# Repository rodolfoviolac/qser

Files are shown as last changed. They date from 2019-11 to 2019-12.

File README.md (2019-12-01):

# QSER

QSER is a application and hardware shield interface to manage and fully control a engine motor (Quanser Robots) on Galileo v2 shield.
On this repository you will find the shield hardware design under `/shield` and the software resources under `/src`.

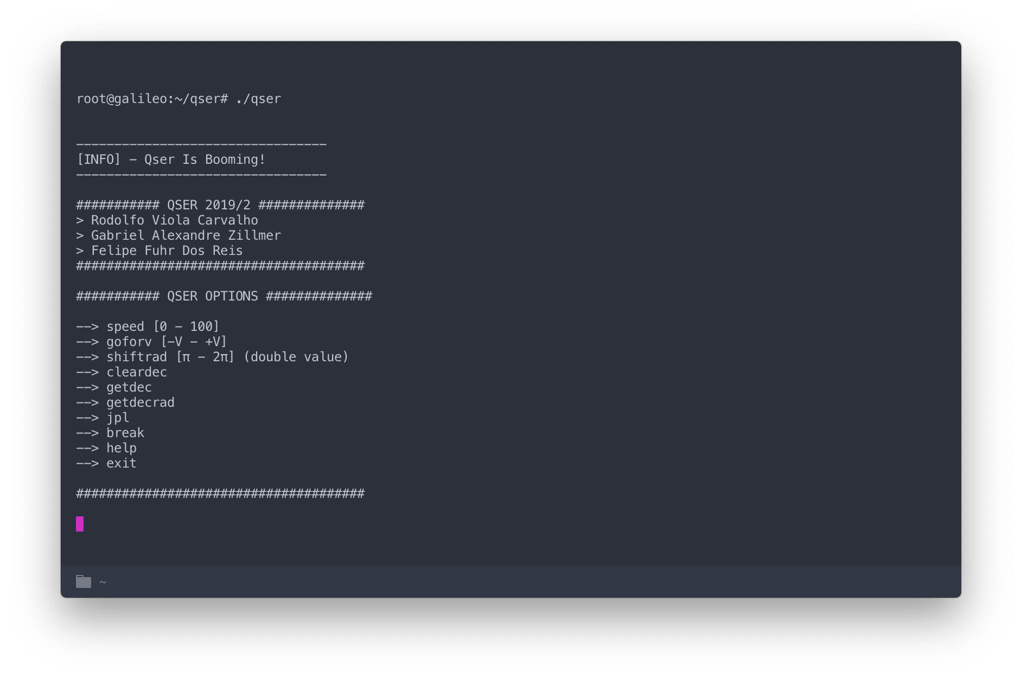
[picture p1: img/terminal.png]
Terminal


## Build

### Project Local 
This project is using cmake to automate build releases and versioning.
- Compile the full project with `/cmake-build-release/make`.
- Clean built files with `/cmake-build-release/make clean`.

### Project Target Galileo
- Compile the full project with `make`.
- Clean built files with `make clean`.

### Documentation
Compile the project documentation to `docs/` folder.
```
  $ make docs
```

## Modules

#### Debugger:
This project contain a built in debugger for handling execution path helping the developers find out eventual bugs or errors.
To enable this feature you need to enable the debugger options under `/src/helpers/helpers.h`.

#### Run Local:
This project contain a local template simulation to help developers simulate the code that will run on the Galileo shield, this feature enable developers to build and run the code without the physical shield device. 
To enable this feature you need to enable the Run Local option under `/src/helpers/helpers.h`.

## Roadmap

See the [open issues](https://github.com/rodolfoviolac/qser/issues) for a list of proposed features (and known issues).

## Contributing

For major changes, please open an issue first to discuss what you would like to change.
Please make sure to update tests as appropriate.

1. Fork the Project
2. Create your Feature Branch (`git checkout -b feature/AmazingFeature`)
3. Commit your Changes (`git commit -m 'Add some AmazingFeature'`)
4. Push to the Branch (`git push origin feature/AmazingFeature`)
5. Open a Pull Request

## Team

> Or Contributors

| <a href="https://github.com/rodolfoviolac" target="_blank">**Rodolfo Viola**</a> | <a href="https://github.com/gazillmer" target="_blank">**Gabriel Zillmer**</a> | <a href="https://github.com/felipefuhr" target="_blank">**Felipe Fuhr**</a> |
| :---: |:---:| :---:|
| rodolfoviolac (https://github.com/rodolfoviolac) | gazillmer (https://github.com/gazillmer) | [![felipefuhr]()](https://github.com/felipefuhr)  |
| <a href="https://github.com/rodolfoviolac" target="_blank">`github.com/rodolfoviolac`</a> | <a href="https://github.com/gazillmer" target="_blank">`github.com/gazillmer`</a> | <a href="https://github.com/felipefuhr" target="_blank">`github.com/felipefuhr`</a> |

## License
[MIT](https://github.com/rodolfoviolac/qser/LICENSE.md)

Project Link: [https://github.com/rodolfoviolac/qser](https://github.com/rodolfoviolac/qser)

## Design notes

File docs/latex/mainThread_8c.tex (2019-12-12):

\hypertarget{mainThread_8c}{}\doxysection{src/main\+Thread/main\+Thread.c File Reference}
\label{mainThread_8c}\index{src/mainThread/mainThread.c@{src/mainThread/mainThread.c}}

Thread Principal para controlar fluxo do usuário e comandos.  

{\ttfamily \#include \char`\"{}main\+Thread.\+h\char`\"{}}\newline
\doxysubsection*{Functions}
\begin{DoxyCompactItemize}
\item 
void $\ast$ \mbox{\hyperlink{mainThread_8c_a59426b0c771489c349fbd9ddc7cf9f7a}{handler\+Main\+Thread}} ()
\begin{DoxyCompactList}\small\item\em Main Thread para interface com usuário e controle de fluxo. Thread responsável por esperar comando do usuário e fazer a chamad necessária da A\+PI para executar a ação. \end{DoxyCompactList}\end{DoxyCompactItemize}
\doxysubsection*{Variables}
\begin{DoxyCompactItemize}
\item 
\mbox{\Hypertarget{mainThread_8c_a1516fc9ce70a57d79877afa8ef7921f7}\label{mainThread_8c_a1516fc9ce70a57d79877afa8ef7921f7}} 
int \mbox{\hyperlink{mainThread_8c_a1516fc9ce70a57d79877afa8ef7921f7}{J\+P\+L\+\_\+\+R\+E\+A\+C\+H\+E\+D\+\_\+\+S\+T\+A\+T\+U\+S\+\_\+\+O\+NE}} = 0
\begin{DoxyCompactList}\small\item\em Status do final de curso um. \end{DoxyCompactList}\item 
\mbox{\Hypertarget{mainThread_8c_aa084c4495d7058b83b56b41864c10846}\label{mainThread_8c_aa084c4495d7058b83b56b41864c10846}} 
int \mbox{\hyperlink{mainThread_8c_aa084c4495d7058b83b56b41864c10846}{J\+P\+L\+\_\+\+R\+E\+A\+C\+H\+E\+D\+\_\+\+S\+T\+A\+T\+U\+S\+\_\+\+T\+WO}} = 0
\begin{DoxyCompactList}\small\item\em Status do final de curso dois. \end{DoxyCompactList}\end{DoxyCompactItemize}

\doxysubsection{Detailed Description}
Thread Principal para controlar fluxo do usuário e comandos. 

\begin{DoxyAuthor}{Author}
Rodolfo Viola Carvalho, Gabriel Alexandre Zillmer, Felipe Fuhr Dos Reis 
\end{DoxyAuthor}
\begin{DoxyDate}{Date}
11 Dec 2019 
\end{DoxyDate}

\doxysubsection{Function Documentation}
\mbox{\Hypertarget{mainThread_8c_a59426b0c771489c349fbd9ddc7cf9f7a}\label{mainThread_8c_a59426b0c771489c349fbd9ddc7cf9f7a}} 
\index{mainThread.c@{mainThread.c}!handlerMainThread@{handlerMainThread}}
\index{handlerMainThread@{handlerMainThread}!mainThread.c@{mainThread.c}}
\doxysubsubsection{\texorpdfstring{handlerMainThread()}{handlerMainThread()}}
{\footnotesize\ttfamily void$\ast$ handler\+Main\+Thread (\begin{DoxyParamCaption}{ }\end{DoxyParamCaption})}

Main Thread para interface com usuário e controle de fluxo. Thread responsável por esperar comando do usuário e fazer a chamad necessária da A\+PI para executar a ação. 

É nessa thread que é feita excutada as funções da biblioteca, repetidamente espera em um loop infito um comando de um usuário para sair e encerrar o programa é necessario um comando Exit.

\begin{DoxyReturn}{Returns}
Retorna um Ponteiro para Null 
\end{DoxyReturn}
Função para Setar Posição de Target em Radianos.

Essa Rotina é responsável por fazer o cálculo de conversão de Radianos para uma posição do motor; Do datasheet do motor temos que 1 revolução é igual a 4096 counts. (4096 / 360) = 1 grau ou 0.\+0174533 rad

Leitura do decoder e transformação para Radianos.

Essa Rotina é responsável por fazer o cálculo de conversão da leitura do decoder para posição em radianos; Do datasheet do motor temos que 1 revolução é igual a 4096 counts. (4096 / 360) = 1 grau ou 0.\+0174533 rad

Definition at line 40 of file main\+Thread.\+c.

\begin{DoxyCode}{0}
\DoxyCodeLine{40                           \{}
\DoxyCodeLine{41     \textcolor{keywordflow}{if}(\mbox{\hyperlink{helpers_8h_ad72dbcf6d0153db1b8d8a58001feed83}{DEBUG}}) printf(\textcolor{stringliteral}{"[DEBUG] -\/ Starting handlerMainThread \(\backslash\)n"});}
\DoxyCodeLine{42     \mbox{\hyperlink{userInterface_8c_ad08d5cb2ed8e6805573049fd31dab2db}{printUserGroupsName}}();}
\DoxyCodeLine{43     \mbox{\hyperlink{userInterface_8c_a4b9e2beb67256f2c06b39d24bc83e28d}{printUserOptions}}();}
\DoxyCodeLine{44 }
\DoxyCodeLine{45     \textcolor{keywordtype}{char} command[100];}
\DoxyCodeLine{46     \textcolor{keywordflow}{while} (fgets(command, \textcolor{keyword}{sizeof}(command), stdin)) \{}
\DoxyCodeLine{47         \textcolor{keywordflow}{if}(\mbox{\hyperlink{helpers_8h_ad72dbcf6d0153db1b8d8a58001feed83}{DEBUG}}) printf(\textcolor{stringliteral}{"[DEBUG] -\/ Inside Command While MainThread \(\backslash\)n"});}
\DoxyCodeLine{48         \textcolor{keywordflow}{switch} (\mbox{\hyperlink{userInterface_8c_ace06aeff812973e632f2da24f34dcd39}{resolveOption}}(command)) \{}
\DoxyCodeLine{49             \textcolor{keywordflow}{case} OPTION\_SPEED: \{}
\DoxyCodeLine{50                 \textcolor{keywordflow}{if}(\mbox{\hyperlink{helpers_8h_ad72dbcf6d0153db1b8d8a58001feed83}{DEBUG}}) printf(\textcolor{stringliteral}{"[DEBUG] -\/ Got SPEED Option MainThread \(\backslash\)n"});}
\DoxyCodeLine{51                 \textcolor{keywordtype}{float} commandAmount = atof(\&command[6]);}
\DoxyCodeLine{52                 \textcolor{keywordflow}{if}(commandAmount > 100 || commandAmount < 0) \{}
\DoxyCodeLine{53                     printf(\textcolor{stringliteral}{"[ERROR] -\/ Speed Amount Must Be [0-\/100]\(\backslash\)n"});}
\DoxyCodeLine{54                 \} \textcolor{keywordflow}{else} \{}
\DoxyCodeLine{55                     \textcolor{keywordflow}{if}(\mbox{\hyperlink{helpers_8h_ad72dbcf6d0153db1b8d8a58001feed83}{DEBUG}}) printf(\textcolor{stringliteral}{"[DEBUG] -\/ Got Valid Speed Number MainThread \(\backslash\)n"});}
\DoxyCodeLine{56                     \textcolor{keywordtype}{float} dcAmount = (commandAmount/100)*atof(\mbox{\hyperlink{quanserInterface_8h_aacaca0988244bd3a888ca5befa89f44b}{PWM\_PERIOD}});}
\DoxyCodeLine{57                     \textcolor{keywordflow}{if}(\mbox{\hyperlink{quanserInterface_8c_a72cb6672e7a2002cb3eed86f8d58781f}{handlePwm}}((\textcolor{keywordtype}{int})dcAmount) == 1) \{}
\DoxyCodeLine{58                         fprintf(stdout, \textcolor{stringliteral}{"[INFO] MT -\/ Motor Duty Cycle \%d\%\%\(\backslash\)n\(\backslash\)n"}, (\textcolor{keywordtype}{int})dcAmount/10000);}
\DoxyCodeLine{59                     \} \textcolor{keywordflow}{else} \{}
\DoxyCodeLine{60                         printf(\textcolor{stringliteral}{"[ERROR] MT -\/ Error Turning On Motor\(\backslash\)n\(\backslash\)n"});}
\DoxyCodeLine{61                     \}}
\DoxyCodeLine{62                 \}}
\DoxyCodeLine{63                 \textcolor{keywordflow}{break};}
\DoxyCodeLine{64             \}}
\DoxyCodeLine{65             \textcolor{keywordflow}{case} OPTION\_JPL: \{}
\DoxyCodeLine{66                 \textcolor{keywordflow}{if}(\mbox{\hyperlink{helpers_8h_ad72dbcf6d0153db1b8d8a58001feed83}{DEBUG}}) printf(\textcolor{stringliteral}{"[DEBUG] -\/ Got JPL Option MainThread \(\backslash\)n"});}
\DoxyCodeLine{67                 \textcolor{keywordflow}{if}(\mbox{\hyperlink{mainThread_8c_a1516fc9ce70a57d79877afa8ef7921f7}{JPL\_REACHED\_STATUS\_ONE}} == JPL\_REACHED)\{}
\DoxyCodeLine{68                     printf(\textcolor{stringliteral}{"[INFO] MT -\/ JPL ONE Reached The End. State: Active [ \%d ]\(\backslash\)n"}, \mbox{\hyperlink{mainThread_8c_a1516fc9ce70a57d79877afa8ef7921f7}{JPL\_REACHED\_STATUS\_ONE}});}
\DoxyCodeLine{69                 \} \textcolor{keywordflow}{else} printf(\textcolor{stringliteral}{"[INFO] MT -\/ READ JPL ONE. State: Inactive [ \%d ]\(\backslash\)n"}, \mbox{\hyperlink{mainThread_8c_a1516fc9ce70a57d79877afa8ef7921f7}{JPL\_REACHED\_STATUS\_ONE}});}
\DoxyCodeLine{70                 \textcolor{keywordflow}{if}(\mbox{\hyperlink{mainThread_8c_aa084c4495d7058b83b56b41864c10846}{JPL\_REACHED\_STATUS\_TWO}} == JPL\_REACHED)\{}
\DoxyCodeLine{71                     printf(\textcolor{stringliteral}{"[INFO] MT -\/ JPL TWO Reached The End. State: Active [ \%d ]\(\backslash\)n\(\backslash\)n"}, \mbox{\hyperlink{mainThread_8c_aa084c4495d7058b83b56b41864c10846}{JPL\_REACHED\_STATUS\_TWO}});}
\DoxyCodeLine{72                 \} \textcolor{keywordflow}{else} printf(\textcolor{stringliteral}{"[INFO] MT -\/ READ JPL TWO. State: Inactive [ \%d ]\(\backslash\)n\(\backslash\)n"}, \mbox{\hyperlink{mainThread_8c_aa084c4495d7058b83b56b41864c10846}{JPL\_REACHED\_STATUS\_TWO}});}
\DoxyCodeLine{73                 \textcolor{keywordflow}{break};}
\DoxyCodeLine{74             \}}
\DoxyCodeLine{75             \textcolor{keywordflow}{case} OPTION\_GO\_FOR\_V: \{}
\DoxyCodeLine{76                 \textcolor{keywordflow}{if}(\mbox{\hyperlink{helpers_8h_ad72dbcf6d0153db1b8d8a58001feed83}{DEBUG}}) printf(\textcolor{stringliteral}{"[DEBUG] -\/ Got GO FOR V Option MainThread \(\backslash\)n"});}
\DoxyCodeLine{77                 \textcolor{keywordtype}{float} commandAmount = atof(\&command[7]);}
\DoxyCodeLine{78                 \textcolor{keywordflow}{if}(commandAmount < -\/QSER\_VOLTAGE || commandAmount > \mbox{\hyperlink{quanserInterface_8h_a85d3bb9e37fcff0e990ccd0ecb50f169}{QSER\_VOLTAGE}}) \{}
\DoxyCodeLine{79                     fprintf(stderr, \textcolor{stringliteral}{"[ERROR] -\/ Voltage Must Be On The Interval [\%+d,\%+d]\(\backslash\)n"}, (\textcolor{keywordtype}{int}) -\/\mbox{\hyperlink{quanserInterface_8h_a85d3bb9e37fcff0e990ccd0ecb50f169}{QSER\_VOLTAGE}}, (\textcolor{keywordtype}{int}) \mbox{\hyperlink{quanserInterface_8h_a85d3bb9e37fcff0e990ccd0ecb50f169}{QSER\_VOLTAGE}});}
\DoxyCodeLine{80                 \} \textcolor{keywordflow}{else} \{}
\DoxyCodeLine{81                     \textcolor{keywordflow}{if}(\mbox{\hyperlink{helpers_8h_ad72dbcf6d0153db1b8d8a58001feed83}{DEBUG}}) printf(\textcolor{stringliteral}{"[DEBUG] MT -\/ Got Accepted Voltage \(\backslash\)n"});}
\DoxyCodeLine{82                     \textcolor{keywordflow}{if}(\mbox{\hyperlink{quanserInterface_8c_a0c496c62c73c815a5b92cd2935452dbb}{qserVoltage}}(commandAmount) == 1)  \{}
\DoxyCodeLine{83                         fprintf(stdout, \textcolor{stringliteral}{"[INFO] -\/ Motor Triggered With Voltage  \%+.1fV\(\backslash\)n\(\backslash\)n"}, commandAmount);}
\DoxyCodeLine{84                     \} \textcolor{keywordflow}{else} \{}
\DoxyCodeLine{85                         fprintf(stdout, \textcolor{stringliteral}{"[ERROR] -\/ Something Went Wrong Trying To Turn On Motor\(\backslash\)n\(\backslash\)n"});}
\DoxyCodeLine{86                     \}}
\DoxyCodeLine{87                 \}}
\DoxyCodeLine{88                 \textcolor{keywordflow}{break};}
\DoxyCodeLine{89             \}}
\DoxyCodeLine{90             \textcolor{keywordflow}{case} OPTION\_QSER\_BREAK: \{}
\DoxyCodeLine{91                 \textcolor{keywordflow}{if}(\mbox{\hyperlink{helpers_8h_ad72dbcf6d0153db1b8d8a58001feed83}{DEBUG}}) printf(\textcolor{stringliteral}{"[DEBUG] -\/ Got QSER BREAK Option MainThread\(\backslash\)n"});}
\DoxyCodeLine{92                 \textcolor{keywordflow}{if}(\mbox{\hyperlink{quanserInterface_8c_a0cd1c4a8a39f9776767a0a1c843e51f1}{qserBreak}}() == TRUE)\{}
\DoxyCodeLine{93                     \mbox{\hyperlink{pidController_8c_aa2a62b6c21f82bd7e19c63e02d2cf01c}{turnOffPid}}();}
\DoxyCodeLine{94                     printf(\textcolor{stringliteral}{"[INFO] -\/ Breaking Motor\(\backslash\)n"});}
\DoxyCodeLine{95                 \} \textcolor{keywordflow}{else} \{}
\DoxyCodeLine{96                     fprintf(stdout, \textcolor{stringliteral}{"[ERROR] -\/ Something Went Wrong Trying To Break Motor\(\backslash\)n\(\backslash\)n"});}
\DoxyCodeLine{97                 \}}
\DoxyCodeLine{98                 \textcolor{keywordflow}{break};}
\DoxyCodeLine{99             \}}
\DoxyCodeLine{107             \textcolor{keywordflow}{case} OPTION\_SHIFT\_RAD: \{}
\DoxyCodeLine{108                 \textcolor{keywordflow}{if}(\mbox{\hyperlink{helpers_8h_ad72dbcf6d0153db1b8d8a58001feed83}{DEBUG}}) printf(\textcolor{stringliteral}{"[DEBUG] -\/ Got OPTION\_SHIFT\_RAD Option MainThread\(\backslash\)n"});}
\DoxyCodeLine{109                 \textcolor{keywordtype}{double} commandAmount = (double)strtof(\&command[9], NULL);}
\DoxyCodeLine{110                 \textcolor{keywordflow}{if}(commandAmount < 0 || commandAmount > \mbox{\hyperlink{helpers_8h_a598a3330b3c21701223ee0ca14316eca}{PI}})\{}
\DoxyCodeLine{111                     printf(\textcolor{stringliteral}{"[Error] -\/ Radian Must Be On The Interval [0, \%f] \(\backslash\)n"}, \mbox{\hyperlink{helpers_8h_a598a3330b3c21701223ee0ca14316eca}{PI}});}
\DoxyCodeLine{112                     \textcolor{keywordflow}{break};}
\DoxyCodeLine{113                 \}}
\DoxyCodeLine{114                 \textcolor{keywordtype}{int} targetMotorPosition = commandAmount * (MAX\_RANGE / \mbox{\hyperlink{helpers_8h_a598a3330b3c21701223ee0ca14316eca}{PI}}) * \mbox{\hyperlink{quanserInterface_8h_a4e111c8fe62388ff42a9878355034406}{MOTOR\_REVOLUTIONS}};}
\DoxyCodeLine{115                 \mbox{\hyperlink{pidController_8c_abe99aea2237bf45370f11475aab83cdd}{setTarget}}(targetMotorPosition);}
\DoxyCodeLine{116                 \mbox{\hyperlink{pidController_8c_ad44a79f712b96530f491cf5a841c9817}{turnOnPid}}();}
\DoxyCodeLine{117                 \textcolor{keywordflow}{break};}
\DoxyCodeLine{118             \}}
\DoxyCodeLine{119             \textcolor{keywordflow}{case} OPTION\_SET\_KD: \{}
\DoxyCodeLine{120                 \textcolor{keywordflow}{if}(\mbox{\hyperlink{helpers_8h_ad72dbcf6d0153db1b8d8a58001feed83}{DEBUG}}) printf(\textcolor{stringliteral}{"[DEBUG] -\/ Got OPTION\_SET\_KD Option MainThread \(\backslash\)n"});}
\DoxyCodeLine{121                 \textcolor{keywordtype}{double} commandAmount = (double)strtof(\&command[6], NULL);}
\DoxyCodeLine{122                 \mbox{\hyperlink{pidController_8c_a0a8eecf482506155e3b690c45f4c4e4b}{setControlKd}}(commandAmount);}
\DoxyCodeLine{123                 \textcolor{keywordflow}{break};}
\DoxyCodeLine{124             \}}
\DoxyCodeLine{125             \textcolor{keywordflow}{case} OPTION\_SET\_KP: \{}
\DoxyCodeLine{126                 \textcolor{keywordflow}{if}(\mbox{\hyperlink{helpers_8h_ad72dbcf6d0153db1b8d8a58001feed83}{DEBUG}}) printf(\textcolor{stringliteral}{"[DEBUG] -\/ Got OPTION\_SET\_KP Option MainThread \(\backslash\)n"});}
\DoxyCodeLine{127                 \textcolor{keywordtype}{double} commandAmount = (double)strtof(\&command[6], NULL);}
\DoxyCodeLine{128                 \mbox{\hyperlink{pidController_8c_a8d8cec964229574d5f0af312a00e5935}{setControlKp}}(commandAmount);}
\DoxyCodeLine{129                 \textcolor{keywordflow}{break};}
\DoxyCodeLine{130             \}}
\DoxyCodeLine{131             \textcolor{keywordflow}{case} OPTION\_SET\_KI: \{}
\DoxyCodeLine{132                 \textcolor{keywordflow}{if}(\mbox{\hyperlink{helpers_8h_ad72dbcf6d0153db1b8d8a58001feed83}{DEBUG}}) printf(\textcolor{stringliteral}{"[DEBUG] -\/ Got OPTION\_SET\_KI Option MainThread \(\backslash\)n"});}
\DoxyCodeLine{133                 \textcolor{keywordtype}{double} commandAmount = (double)strtof(\&command[6], NULL);}
\DoxyCodeLine{134                 \mbox{\hyperlink{pidController_8c_a315d3a9847f641c407ef6b32a65fd640}{setControlKi}}(commandAmount);}
\DoxyCodeLine{135                 \textcolor{keywordflow}{break};}
\DoxyCodeLine{136             \}}
\DoxyCodeLine{137             \textcolor{keywordflow}{case} OPTION\_CLEAR\_DEC: \{}
\DoxyCodeLine{138                 \textcolor{keywordflow}{if}(\mbox{\hyperlink{helpers_8h_ad72dbcf6d0153db1b8d8a58001feed83}{DEBUG}}) printf(\textcolor{stringliteral}{"[DEBUG] -\/ Got OPTION\_CLEAR\_DEC Option MainThread\(\backslash\)n"});}
\DoxyCodeLine{139                 \mbox{\hyperlink{decoderInterface_8c_a82fe1a26c4a03de6dc52798635d4ca27}{clearDecoder}}();}
\DoxyCodeLine{140                 printf(\textcolor{stringliteral}{"[INFO] -\/ Cleaning Decoder\(\backslash\)n\(\backslash\)n"});}
\DoxyCodeLine{141                 \textcolor{keywordflow}{break};}
\DoxyCodeLine{142             \}}
\DoxyCodeLine{143             \textcolor{keywordflow}{case} OPTION\_READ\_DEC: \{}
\DoxyCodeLine{144                 \textcolor{keywordflow}{if}(\mbox{\hyperlink{helpers_8h_ad72dbcf6d0153db1b8d8a58001feed83}{DEBUG}}) printf(\textcolor{stringliteral}{"[DEBUG] -\/ Got OPTION\_READ\_DEC Option MainThread\(\backslash\)n"});}
\DoxyCodeLine{145                 \textcolor{keywordtype}{int} counterDecoder = \mbox{\hyperlink{decoderInterface_8c_af5872793a562a54c455d94fef27f3a2b}{readDecoderCounter}}();}
\DoxyCodeLine{146                 printf(\textcolor{stringliteral}{"[INFO] -\/ Decoder Reading: \%d \(\backslash\)n\(\backslash\)n"}, counterDecoder);}
\DoxyCodeLine{147                 \textcolor{keywordflow}{break};}
\DoxyCodeLine{148             \}}
\DoxyCodeLine{156             \textcolor{keywordflow}{case} OPTION\_READ\_DEC\_RAD: \{}
\DoxyCodeLine{157                 \textcolor{keywordflow}{if}(\mbox{\hyperlink{helpers_8h_ad72dbcf6d0153db1b8d8a58001feed83}{DEBUG}}) printf(\textcolor{stringliteral}{"[DEBUG] -\/ Got OPTION\_READ\_DEC\_RAD Option MainThread\(\backslash\)n"});}
\DoxyCodeLine{158                 \textcolor{keywordtype}{int} counterDecoder = \mbox{\hyperlink{decoderInterface_8c_af5872793a562a54c455d94fef27f3a2b}{readDecoderCounter}}();}
\DoxyCodeLine{159                 \textcolor{keywordtype}{double} revCount = (float)counterDecoder / \mbox{\hyperlink{quanserInterface_8h_a4e111c8fe62388ff42a9878355034406}{MOTOR\_REVOLUTIONS}};}
\DoxyCodeLine{160                 \textcolor{keywordtype}{double} radDec = revCount * \mbox{\hyperlink{helpers_8h_a598a3330b3c21701223ee0ca14316eca}{PI}} / MAX\_RANGE;}
\DoxyCodeLine{161                 printf(\textcolor{stringliteral}{"[INFO] -\/ Decoder Reading: \%f \(\backslash\)n\(\backslash\)n"}, radDec);}
\DoxyCodeLine{162                 \textcolor{keywordflow}{break};}
\DoxyCodeLine{163             \}}
\DoxyCodeLine{164             \textcolor{keywordflow}{case} OPTION\_HELP: \{}
\DoxyCodeLine{165                 \textcolor{keywordflow}{if}(\mbox{\hyperlink{helpers_8h_ad72dbcf6d0153db1b8d8a58001feed83}{DEBUG}}) printf(\textcolor{stringliteral}{"[DEBUG] -\/ Got HELP Option MainThread\(\backslash\)n"});}
\DoxyCodeLine{166                 \mbox{\hyperlink{userInterface_8c_a4b9e2beb67256f2c06b39d24bc83e28d}{printUserOptions}}();}
\DoxyCodeLine{167                 \textcolor{keywordflow}{break};}
\DoxyCodeLine{168             \}}
\DoxyCodeLine{169             \textcolor{keywordflow}{case} OPTION\_EXIT: \{}
\DoxyCodeLine{170                 \textcolor{keywordflow}{if}(\mbox{\hyperlink{helpers_8h_ad72dbcf6d0153db1b8d8a58001feed83}{DEBUG}}) printf(\textcolor{stringliteral}{"[DEBUG] -\/ Got EXIT Option MainThread\(\backslash\)n"});}
\DoxyCodeLine{171                 \mbox{\hyperlink{quanserInterface_8c_a0cd1c4a8a39f9776767a0a1c843e51f1}{qserBreak}}();}
\DoxyCodeLine{172                 \mbox{\hyperlink{pidController_8c_aa2a62b6c21f82bd7e19c63e02d2cf01c}{turnOffPid}}();}
\DoxyCodeLine{173                 \mbox{\hyperlink{decoderInterface_8c_a75971fdf1e347a1d330cae5e15250edf}{wrapUpDecoder}}();}
\DoxyCodeLine{174                 printf(\textcolor{stringliteral}{"[INFO] -\/ Finishing Application...\(\backslash\)n"});}
\DoxyCodeLine{175                 exit(0);}
\DoxyCodeLine{176             \}}
\DoxyCodeLine{177             \textcolor{keywordflow}{case} \mbox{\hyperlink{userInterface_8h_a58a559802dc87f303b0505b79f28a4fc}{OPTION\_INVALID}}: \{}
\DoxyCodeLine{178                 \textcolor{keywordflow}{if}(\mbox{\hyperlink{helpers_8h_ad72dbcf6d0153db1b8d8a58001feed83}{DEBUG}}) printf(\textcolor{stringliteral}{"[DEBUG] -\/ Got INVALID Option MainThread\(\backslash\)n"});}
\DoxyCodeLine{179                 printf(\textcolor{stringliteral}{"[ERROR] -\/ Command Invalid Type Help For The Command List\(\backslash\)n"});}
\DoxyCodeLine{180                 \textcolor{keywordflow}{break};}
\DoxyCodeLine{181             \}}
\DoxyCodeLine{182             \textcolor{keywordflow}{default}: \{}
\DoxyCodeLine{183                 \textcolor{keywordflow}{if}(\mbox{\hyperlink{helpers_8h_ad72dbcf6d0153db1b8d8a58001feed83}{DEBUG}}) printf(\textcolor{stringliteral}{"[DEBUG] -\/ Got DEFAULT Option MainThread\(\backslash\)n"});}
\DoxyCodeLine{184                 printf(\textcolor{stringliteral}{"[ERROR] -\/ Command Invalid Type Help For The Command List\(\backslash\)n"});}
\DoxyCodeLine{185             \}}
\DoxyCodeLine{186         \}}
\DoxyCodeLine{187     \}}
\DoxyCodeLine{188     \textcolor{keywordflow}{return} NULL;}
\DoxyCodeLine{189 \}}

\end{DoxyCode}

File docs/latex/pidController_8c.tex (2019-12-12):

\hypertarget{pidController_8c}{}\doxysection{src/pid\+Controller/pid\+Controller.c File Reference}
\label{pidController_8c}\index{src/pidController/pidController.c@{src/pidController/pidController.c}}

Interfaces do P\+ID e controle de suas funcionalidades.  

{\ttfamily \#include \char`\"{}pid\+Controller.\+h\char`\"{}}\newline
\doxysubsection*{Functions}
\begin{DoxyCompactItemize}
\item 
int \mbox{\hyperlink{pidController_8c_abe99aea2237bf45370f11475aab83cdd}{set\+Target}} (int new\+Target)
\begin{DoxyCompactList}\small\item\em Função para setar nova posição. Rotina responsável por setar uma nova posição desejada. É nesta função que são zerados os valores de parte de erros e outras variáveis já calculadas. A nova posição é convertida e armazenada em target\+Location. \end{DoxyCompactList}\item 
void \mbox{\hyperlink{pidController_8c_ad44a79f712b96530f491cf5a841c9817}{turn\+On\+Pid}} ()
\begin{DoxyCompactList}\small\item\em Função para ligar o Pid. Rotina responsável Por Ligar O P\+ID. \end{DoxyCompactList}\item 
void \mbox{\hyperlink{pidController_8c_aa2a62b6c21f82bd7e19c63e02d2cf01c}{turn\+Off\+Pid}} ()
\begin{DoxyCompactList}\small\item\em Função para desligar o Pid Rotina responsável por desligar O P\+ID. \end{DoxyCompactList}\item 
void \mbox{\hyperlink{pidController_8c_a8d8cec964229574d5f0af312a00e5935}{set\+Control\+Kp}} (double new\+Kp)
\begin{DoxyCompactList}\small\item\em Função para setar Kp. Rotina Repsonsavel por Setar Kp, valor parte da integral. \end{DoxyCompactList}\item 
void \mbox{\hyperlink{pidController_8c_a0a8eecf482506155e3b690c45f4c4e4b}{set\+Control\+Kd}} (double new\+Kd)
\begin{DoxyCompactList}\small\item\em Função para setar Kd. Rotina responsável por Setar Kd, valor parte da integral. \end{DoxyCompactList}\item 
void \mbox{\hyperlink{pidController_8c_a315d3a9847f641c407ef6b32a65fd640}{set\+Control\+Ki}} (double new\+Ki)
\begin{DoxyCompactList}\small\item\em Função para setar Ki. Rotina responsável por setar Ki, valor parte da integral. \end{DoxyCompactList}\item 
double \mbox{\hyperlink{pidController_8c_ad2327b73379de6859aafb872d874273d}{pid\+Handler}} (int current\+Position)
\begin{DoxyCompactList}\small\item\em Função Principal do P\+ID Para Cálculo de Tensão. Rotina Para fazer os cálculos do P\+ID e suas variáveis tal como desvios e erros, retornando o valor de tensao que deve ser aplicado no motor. \end{DoxyCompactList}\end{DoxyCompactItemize}
\doxysubsection*{Variables}
\begin{DoxyCompactItemize}
\item 
\mbox{\Hypertarget{pidController_8c_a8467e669549465248016d01cc5f9f0ad}\label{pidController_8c_a8467e669549465248016d01cc5f9f0ad}} 
double \mbox{\hyperlink{pidController_8c_a8467e669549465248016d01cc5f9f0ad}{control\+Ki}} = 0.\+0
\begin{DoxyCompactList}\small\item\em Define Parte de Controle de Ki. \end{DoxyCompactList}\item 
\mbox{\Hypertarget{pidController_8c_add21ccb04e1708df9847b3537c3c160d}\label{pidController_8c_add21ccb04e1708df9847b3537c3c160d}} 
double \mbox{\hyperlink{pidController_8c_add21ccb04e1708df9847b3537c3c160d}{control\+Kp}} = 0.\+005
\begin{DoxyCompactList}\small\item\em Define Parte de Controle de Kp. \end{DoxyCompactList}\item 
\mbox{\Hypertarget{pidController_8c_ab032dbb879b584cedb078654339a3a97}\label{pidController_8c_ab032dbb879b584cedb078654339a3a97}} 
double \mbox{\hyperlink{pidController_8c_ab032dbb879b584cedb078654339a3a97}{control\+Kd}} = 0.\+0
\begin{DoxyCompactList}\small\item\em Define Parte de Controle de Kd. \end{DoxyCompactList}\item 
\mbox{\Hypertarget{pidController_8c_af1f929809645dc5607b842219108dadf}\label{pidController_8c_af1f929809645dc5607b842219108dadf}} 
int \mbox{\hyperlink{pidController_8c_af1f929809645dc5607b842219108dadf}{target\+Location}} = 0
\begin{DoxyCompactList}\small\item\em Define uma posição de destino. \end{DoxyCompactList}\item 
\mbox{\Hypertarget{pidController_8c_a900bffdedb5b76779215d899eaac9235}\label{pidController_8c_a900bffdedb5b76779215d899eaac9235}} 
double \mbox{\hyperlink{pidController_8c_a900bffdedb5b76779215d899eaac9235}{error\+Deviation}} = 0.\+00
\begin{DoxyCompactList}\small\item\em Define o desvio do erro. \end{DoxyCompactList}\item 
\mbox{\Hypertarget{pidController_8c_a380c7113c9f7b43e21e5d9ff303413a9}\label{pidController_8c_a380c7113c9f7b43e21e5d9ff303413a9}} 
double \mbox{\hyperlink{pidController_8c_a380c7113c9f7b43e21e5d9ff303413a9}{all\+Errors\+Summation}} = 0.\+0
\begin{DoxyCompactList}\small\item\em Define somatório de todos os erros. \end{DoxyCompactList}\item 
\mbox{\Hypertarget{pidController_8c_a11837efa2f154aaa978a9c69a16e88e2}\label{pidController_8c_a11837efa2f154aaa978a9c69a16e88e2}} 
int \mbox{\hyperlink{pidController_8c_a11837efa2f154aaa978a9c69a16e88e2}{pid\+Status}} = 0
\begin{DoxyCompactList}\small\item\em Define o Status do P\+ID. \end{DoxyCompactList}\end{DoxyCompactItemize}

\doxysubsection{Detailed Description}
Interfaces do P\+ID e controle de suas funcionalidades. 

\begin{DoxyAuthor}{Author}
Rodolfo Viola Carvalho, Gabriel Alexandre Zillmer, Felipe Fuhr Dos Reis 
\end{DoxyAuthor}
\begin{DoxyDate}{Date}
11 Dec 2019 
\end{DoxyDate}

\doxysubsection{Function Documentation}
\mbox{\Hypertarget{pidController_8c_ad2327b73379de6859aafb872d874273d}\label{pidController_8c_ad2327b73379de6859aafb872d874273d}} 
\index{pidController.c@{pidController.c}!pidHandler@{pidHandler}}
\index{pidHandler@{pidHandler}!pidController.c@{pidController.c}}
\doxysubsubsection{\texorpdfstring{pidHandler()}{pidHandler()}}
{\footnotesize\ttfamily double pid\+Handler (\begin{DoxyParamCaption}\item[{int}]{current\+Position }\end{DoxyParamCaption})}

Função Principal do P\+ID Para Cálculo de Tensão. Rotina Para fazer os cálculos do P\+ID e suas variáveis tal como desvios e erros, retornando o valor de tensao que deve ser aplicado no motor. 

O cálculo nesta função basea-\/se na leitura atual da posição do motor dessa maneira gera um valor de tensão para que atinja o alvo.

\begin{DoxyParams}{Parameters}
{\em current\+Position} & Posicao Corrente \\
\hline
\end{DoxyParams}
\begin{DoxyReturn}{Returns}
Valor de Tensão que deve ser aplicado no Motor 
\end{DoxyReturn}

Definition at line 126 of file pid\+Controller.\+c.

\begin{DoxyCode}{0}
\DoxyCodeLine{126                                       \{}
\DoxyCodeLine{127     \textcolor{keywordflow}{if}(\mbox{\hyperlink{helpers_8h_ad72dbcf6d0153db1b8d8a58001feed83}{DEBUG}}) printf(\textcolor{stringliteral}{"[DEBUG] -\/ Starting pidHandler pidController \(\backslash\)n"});}
\DoxyCodeLine{128     \textcolor{keywordtype}{double} pidUnitVoltage;}
\DoxyCodeLine{129     \textcolor{keywordtype}{double} pPart;}
\DoxyCodeLine{130     \textcolor{keywordtype}{double} iPart;}
\DoxyCodeLine{131     \textcolor{keywordtype}{double} dPart;}
\DoxyCodeLine{132     \textcolor{keywordtype}{double} deviation;}
\DoxyCodeLine{133     \textcolor{keywordtype}{double} tempErrorDeviation = \mbox{\hyperlink{pidController_8c_af1f929809645dc5607b842219108dadf}{targetLocation}} -\/ currentPosition;}
\DoxyCodeLine{134 }
\DoxyCodeLine{135     \mbox{\hyperlink{pidController_8c_a380c7113c9f7b43e21e5d9ff303413a9}{allErrorsSummation}} += tempErrorDeviation;}
\DoxyCodeLine{136     deviation = tempErrorDeviation -\/ \mbox{\hyperlink{pidController_8c_a900bffdedb5b76779215d899eaac9235}{errorDeviation}};}
\DoxyCodeLine{137     \mbox{\hyperlink{pidController_8c_a900bffdedb5b76779215d899eaac9235}{errorDeviation}} = tempErrorDeviation;}
\DoxyCodeLine{138     pPart = \mbox{\hyperlink{pidController_8c_add21ccb04e1708df9847b3537c3c160d}{controlKp}} * tempErrorDeviation;}
\DoxyCodeLine{139     iPart = \mbox{\hyperlink{pidController_8c_a8467e669549465248016d01cc5f9f0ad}{controlKi}} * \mbox{\hyperlink{pidController_8c_a380c7113c9f7b43e21e5d9ff303413a9}{allErrorsSummation}};}
\DoxyCodeLine{140     dPart = \mbox{\hyperlink{pidController_8c_ab032dbb879b584cedb078654339a3a97}{controlKd}} * deviation;}
\DoxyCodeLine{141 }
\DoxyCodeLine{142     pidUnitVoltage = pPart + iPart + dPart;}
\DoxyCodeLine{143 }
\DoxyCodeLine{144     \textcolor{keywordflow}{if}(pidUnitVoltage > \mbox{\hyperlink{quanserInterface_8h_a85d3bb9e37fcff0e990ccd0ecb50f169}{QSER\_VOLTAGE}}) pidUnitVoltage = \mbox{\hyperlink{quanserInterface_8h_a85d3bb9e37fcff0e990ccd0ecb50f169}{QSER\_VOLTAGE}};}
\DoxyCodeLine{145     \textcolor{keywordflow}{if}(pidUnitVoltage < -\/\mbox{\hyperlink{quanserInterface_8h_a85d3bb9e37fcff0e990ccd0ecb50f169}{QSER\_VOLTAGE}}) pidUnitVoltage = -\/\mbox{\hyperlink{quanserInterface_8h_a85d3bb9e37fcff0e990ccd0ecb50f169}{QSER\_VOLTAGE}};}
\DoxyCodeLine{146 }
\DoxyCodeLine{147     printf(\textcolor{stringliteral}{"[INFO] -\/ PID Voltage Result \%f \(\backslash\)n"}, pidUnitVoltage);}
\DoxyCodeLine{148     \textcolor{keywordflow}{return} pidUnitVoltage;}
\DoxyCodeLine{149 \}}

\end{DoxyCode}
\mbox{\Hypertarget{pidController_8c_a0a8eecf482506155e3b690c45f4c4e4b}\label{pidController_8c_a0a8eecf482506155e3b690c45f4c4e4b}} 
\index{pidController.c@{pidController.c}!setControlKd@{setControlKd}}
\index{setControlKd@{setControlKd}!pidController.c@{pidController.c}}
\doxysubsubsection{\texorpdfstring{setControlKd()}{setControlKd()}}
{\footnotesize\ttfamily void set\+Control\+Kd (\begin{DoxyParamCaption}\item[{double}]{new\+Kd }\end{DoxyParamCaption})}

Função para setar Kd. Rotina responsável por Setar Kd, valor parte da integral. 

\begin{DoxyParams}{Parameters}
{\em Novo} & KD \\
\hline
\end{DoxyParams}

Definition at line 100 of file pid\+Controller.\+c.

\begin{DoxyCode}{0}
\DoxyCodeLine{100                                \{}
\DoxyCodeLine{101     \textcolor{keywordflow}{if}(\mbox{\hyperlink{helpers_8h_ad72dbcf6d0153db1b8d8a58001feed83}{DEBUG}}) printf(\textcolor{stringliteral}{"[DEBUG] -\/ Starting setControlKd pidController \(\backslash\)n"});}
\DoxyCodeLine{102     \mbox{\hyperlink{pidController_8c_ab032dbb879b584cedb078654339a3a97}{controlKd}} = newKd;}
\DoxyCodeLine{103     printf(\textcolor{stringliteral}{"[INFO] -\/ controlKd Value: \%f \(\backslash\)n"}, \mbox{\hyperlink{pidController_8c_ab032dbb879b584cedb078654339a3a97}{controlKd}});}
\DoxyCodeLine{104 \}}

\end{DoxyCode}
\mbox{\Hypertarget{pidController_8c_a315d3a9847f641c407ef6b32a65fd640}\label{pidController_8c_a315d3a9847f641c407ef6b32a65fd640}} 
\index{pidController.c@{pidController.c}!setControlKi@{setControlKi}}
\index{setControlKi@{setControlKi}!pidController.c@{pidController.c}}
\doxysubsubsection{\texorpdfstring{setControlKi()}{setControlKi()}}
{\footnotesize\ttfamily void set\+Control\+Ki (\begin{DoxyParamCaption}\item[{double}]{new\+Ki }\end{DoxyParamCaption})}

Função para setar Ki. Rotina responsável por setar Ki, valor parte da integral. 

\begin{DoxyParams}{Parameters}
{\em Novo} & KI \\
\hline
\end{DoxyParams}

Definition at line 111 of file pid\+Controller.\+c.

\begin{DoxyCode}{0}
\DoxyCodeLine{111                                \{}
\DoxyCodeLine{112     \textcolor{keywordflow}{if}(\mbox{\hyperlink{helpers_8h_ad72dbcf6d0153db1b8d8a58001feed83}{DEBUG}}) printf(\textcolor{stringliteral}{"[DEBUG] -\/ Starting setControlKi pidController \(\backslash\)n"});}
\DoxyCodeLine{113     \mbox{\hyperlink{pidController_8c_a8467e669549465248016d01cc5f9f0ad}{controlKi}} = newKi;}
\DoxyCodeLine{114     printf(\textcolor{stringliteral}{"[INFO] -\/ controlKi Value: \%f \(\backslash\)n"}, \mbox{\hyperlink{pidController_8c_a8467e669549465248016d01cc5f9f0ad}{controlKi}});}
\DoxyCodeLine{115 \}}

\end{DoxyCode}
\mbox{\Hypertarget{pidController_8c_a8d8cec964229574d5f0af312a00e5935}\label{pidController_8c_a8d8cec964229574d5f0af312a00e5935}} 
\index{pidController.c@{pidController.c}!setControlKp@{setControlKp}}
\index{setControlKp@{setControlKp}!pidController.c@{pidController.c}}
\doxysubsubsection{\texorpdfstring{setControlKp()}{setControlKp()}}
{\footnotesize\ttfamily void set\+Control\+Kp (\begin{DoxyParamCaption}\item[{double}]{new\+Kp }\end{DoxyParamCaption})}

Função para setar Kp. Rotina Repsonsavel por Setar Kp, valor parte da integral. 

\begin{DoxyParams}{Parameters}
{\em Novo} & KP \\
\hline
\end{DoxyParams}

Definition at line 89 of file pid\+Controller.\+c.

\begin{DoxyCode}{0}
\DoxyCodeLine{89                                \{}
\DoxyCodeLine{90     \textcolor{keywordflow}{if}(\mbox{\hyperlink{helpers_8h_ad72dbcf6d0153db1b8d8a58001feed83}{DEBUG}}) printf(\textcolor{stringliteral}{"[DEBUG] -\/ Starting setControlKp pidController \(\backslash\)n"});}
\DoxyCodeLine{91     \mbox{\hyperlink{pidController_8c_add21ccb04e1708df9847b3537c3c160d}{controlKp}} = newKp;}
\DoxyCodeLine{92     printf(\textcolor{stringliteral}{"[INFO] -\/ controlKp Value: \%f \(\backslash\)n"}, \mbox{\hyperlink{pidController_8c_add21ccb04e1708df9847b3537c3c160d}{controlKp}});}
\DoxyCodeLine{93 \}}

\end{DoxyCode}
\mbox{\Hypertarget{pidController_8c_abe99aea2237bf45370f11475aab83cdd}\label{pidController_8c_abe99aea2237bf45370f11475aab83cdd}} 
\index{pidController.c@{pidController.c}!setTarget@{setTarget}}
\index{setTarget@{setTarget}!pidController.c@{pidController.c}}
\doxysubsubsection{\texorpdfstring{setTarget()}{setTarget()}}
{\footnotesize\ttfamily int set\+Target (\begin{DoxyParamCaption}\item[{int}]{new\+Target }\end{DoxyParamCaption})}

Função para setar nova posição. Rotina responsável por setar uma nova posição desejada. É nesta função que são zerados os valores de parte de erros e outras variáveis já calculadas. A nova posição é convertida e armazenada em target\+Location. 

\begin{DoxyParams}{Parameters}
{\em new\+Target} & Nova Posicao \\
\hline
\end{DoxyParams}
\begin{DoxyReturn}{Returns}
Retorna Positivo Caso Consiga Setar Nova Posicao. 
\end{DoxyReturn}

Definition at line 48 of file pid\+Controller.\+c.

\begin{DoxyCode}{0}
\DoxyCodeLine{48                              \{}
\DoxyCodeLine{49     \textcolor{keywordflow}{if}(\mbox{\hyperlink{helpers_8h_ad72dbcf6d0153db1b8d8a58001feed83}{DEBUG}}) printf(\textcolor{stringliteral}{"[DEBUG] -\/ Starting setTarget pidController \(\backslash\)n"});}
\DoxyCodeLine{50     \mbox{\hyperlink{pidController_8c_af1f929809645dc5607b842219108dadf}{targetLocation}} = newTarget;}
\DoxyCodeLine{51     \mbox{\hyperlink{pidController_8c_a900bffdedb5b76779215d899eaac9235}{errorDeviation}} = 0.0;}
\DoxyCodeLine{52     \mbox{\hyperlink{pidController_8c_a380c7113c9f7b43e21e5d9ff303413a9}{allErrorsSummation}} = 0.0;}
\DoxyCodeLine{53     printf(\textcolor{stringliteral}{"[INFO] -\/ new Target Location set to \%d \(\backslash\)n"}, \mbox{\hyperlink{pidController_8c_af1f929809645dc5607b842219108dadf}{targetLocation}});}
\DoxyCodeLine{54     \textcolor{keywordflow}{if}(\mbox{\hyperlink{helpers_8h_ad72dbcf6d0153db1b8d8a58001feed83}{DEBUG}}) printf(\textcolor{stringliteral}{"[DEBUG] -\/ Set targetLocation to \%d \(\backslash\)n"}, \mbox{\hyperlink{pidController_8c_af1f929809645dc5607b842219108dadf}{targetLocation}});}
\DoxyCodeLine{55     \textcolor{keywordflow}{return} TRUE;}
\DoxyCodeLine{56 \}}

\end{DoxyCode}
\mbox{\Hypertarget{pidController_8c_aa2a62b6c21f82bd7e19c63e02d2cf01c}\label{pidController_8c_aa2a62b6c21f82bd7e19c63e02d2cf01c}} 
\index{pidController.c@{pidController.c}!turnOffPid@{turnOffPid}}
\index{turnOffPid@{turnOffPid}!pidController.c@{pidController.c}}
\doxysubsubsection{\texorpdfstring{turnOffPid()}{turnOffPid()}}
{\footnotesize\ttfamily void turn\+Off\+Pid (\begin{DoxyParamCaption}{ }\end{DoxyParamCaption})}

Função para desligar o Pid Rotina responsável por desligar O P\+ID. 

\begin{DoxyItemize}
\item \begin{DoxyReturn}{Returns}
Void 
\end{DoxyReturn}

\end{DoxyItemize}

Definition at line 76 of file pid\+Controller.\+c.

\begin{DoxyCode}{0}
\DoxyCodeLine{76                  \{}
\DoxyCodeLine{77     \textcolor{keywordflow}{if}(\mbox{\hyperlink{helpers_8h_ad72dbcf6d0153db1b8d8a58001feed83}{DEBUG}}) printf(\textcolor{stringliteral}{"[DEBUG] -\/ Starting turnOffPidStatus pidController \(\backslash\)n"});}
\DoxyCodeLine{78     \textcolor{keywordflow}{if}(\mbox{\hyperlink{pidController_8c_a11837efa2f154aaa978a9c69a16e88e2}{pidStatus}} == TRUE)\{}
\DoxyCodeLine{79         \textcolor{keywordflow}{if}(\mbox{\hyperlink{helpers_8h_ad72dbcf6d0153db1b8d8a58001feed83}{DEBUG}}) printf(\textcolor{stringliteral}{"[DEBUG] -\/ Setting pidStatus FALSE \(\backslash\)n"});}
\DoxyCodeLine{80         \mbox{\hyperlink{pidController_8c_a11837efa2f154aaa978a9c69a16e88e2}{pidStatus}} = FALSE;}
\DoxyCodeLine{81     \}}
\DoxyCodeLine{82 \}}

\end{DoxyCode}
\mbox{\Hypertarget{pidController_8c_ad44a79f712b96530f491cf5a841c9817}\label{pidController_8c_ad44a79f712b96530f491cf5a841c9817}} 
\index{pidController.c@{pidController.c}!turnOnPid@{turnOnPid}}
\index{turnOnPid@{turnOnPid}!pidController.c@{pidController.c}}
\doxysubsubsection{\texorpdfstring{turnOnPid()}{turnOnPid()}}
{\footnotesize\ttfamily void turn\+On\+Pid (\begin{DoxyParamCaption}{ }\end{DoxyParamCaption})}

Função para ligar o Pid. Rotina responsável Por Ligar O P\+ID. 

\begin{DoxyReturn}{Returns}
Void 
\end{DoxyReturn}

Definition at line 63 of file pid\+Controller.\+c.

\begin{DoxyCode}{0}
\DoxyCodeLine{63                 \{}
\DoxyCodeLine{64     \textcolor{keywordflow}{if}(\mbox{\hyperlink{helpers_8h_ad72dbcf6d0153db1b8d8a58001feed83}{DEBUG}}) printf(\textcolor{stringliteral}{"[DEBUG] -\/ Starting turnOnPidStatus pidController \(\backslash\)n"});}
\DoxyCodeLine{65     \textcolor{keywordflow}{if}(\mbox{\hyperlink{pidController_8c_a11837efa2f154aaa978a9c69a16e88e2}{pidStatus}} == FALSE)\{}
\DoxyCodeLine{66         \textcolor{keywordflow}{if}(\mbox{\hyperlink{helpers_8h_ad72dbcf6d0153db1b8d8a58001feed83}{DEBUG}}) printf(\textcolor{stringliteral}{"[DEBUG] -\/ Setting pidStatus TRUE \(\backslash\)n"});}
\DoxyCodeLine{67         \mbox{\hyperlink{pidController_8c_a11837efa2f154aaa978a9c69a16e88e2}{pidStatus}} = TRUE;}
\DoxyCodeLine{68     \}}
\DoxyCodeLine{69 \}}

\end{DoxyCode}

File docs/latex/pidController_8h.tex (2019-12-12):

\hypertarget{pidController_8h}{}\doxysection{src/pid\+Controller/pid\+Controller.h File Reference}
\label{pidController_8h}\index{src/pidController/pidController.h@{src/pidController/pidController.h}}

Cabeçalho das funções da interface do P\+ID.  

{\ttfamily \#include \char`\"{}../helpers/helpers.\+h\char`\"{}}\newline
{\ttfamily \#include \char`\"{}../quanser\+Interface/quanser\+Interface.\+h\char`\"{}}\newline
\doxysubsection*{Functions}
\begin{DoxyCompactItemize}
\item 
int \mbox{\hyperlink{pidController_8h_abe99aea2237bf45370f11475aab83cdd}{set\+Target}} (int new\+Target)
\begin{DoxyCompactList}\small\item\em Função para setar nova posição. Rotina responsável por setar uma nova posição desejada. É nesta função que são zerados os valores de parte de erros e outras variáveis já calculadas. A nova posição é convertida e armazenada em target\+Location. \end{DoxyCompactList}\item 
void \mbox{\hyperlink{pidController_8h_ad44a79f712b96530f491cf5a841c9817}{turn\+On\+Pid}} ()
\begin{DoxyCompactList}\small\item\em Função para ligar o Pid. Rotina responsável Por Ligar O P\+ID. \end{DoxyCompactList}\item 
void \mbox{\hyperlink{pidController_8h_aa2a62b6c21f82bd7e19c63e02d2cf01c}{turn\+Off\+Pid}} ()
\begin{DoxyCompactList}\small\item\em Função para desligar o Pid Rotina responsável por desligar O P\+ID. \end{DoxyCompactList}\item 
void \mbox{\hyperlink{pidController_8h_a8d8cec964229574d5f0af312a00e5935}{set\+Control\+Kp}} (double new\+Kp)
\begin{DoxyCompactList}\small\item\em Função para setar Kp. Rotina Repsonsavel por Setar Kp, valor parte da integral. \end{DoxyCompactList}\item 
void \mbox{\hyperlink{pidController_8h_a0a8eecf482506155e3b690c45f4c4e4b}{set\+Control\+Kd}} (double new\+Kd)
\begin{DoxyCompactList}\small\item\em Função para setar Kd. Rotina responsável por Setar Kd, valor parte da integral. \end{DoxyCompactList}\item 
void \mbox{\hyperlink{pidController_8h_a315d3a9847f641c407ef6b32a65fd640}{set\+Control\+Ki}} (double new\+Ki)
\begin{DoxyCompactList}\small\item\em Função para setar Ki. Rotina responsável por setar Ki, valor parte da integral. \end{DoxyCompactList}\item 
\mbox{\Hypertarget{pidController_8h_a84419a84b7812ac95cdd67086b4d2585}\label{pidController_8h_a84419a84b7812ac95cdd67086b4d2585}} 
void {\bfseries set\+Conversion\+Coefficient\+Unit} (double new\+Conversion\+Coefficient\+Unit)
\item 
double \mbox{\hyperlink{pidController_8h_ad2327b73379de6859aafb872d874273d}{pid\+Handler}} (int current\+Position)
\begin{DoxyCompactList}\small\item\em Função Principal do P\+ID Para Cálculo de Tensão. Rotina Para fazer os cálculos do P\+ID e suas variáveis tal como desvios e erros, retornando o valor de tensao que deve ser aplicado no motor. \end{DoxyCompactList}\end{DoxyCompactItemize}

\doxysubsection{Detailed Description}
Cabeçalho das funções da interface do P\+ID. 

\begin{DoxyAuthor}{Author}
Rodolfo Viola Carvalho, Gabriel Alexandre Zillmer, Felipe Fuhr Dos Reis 
\end{DoxyAuthor}
\begin{DoxyDate}{Date}
11 Dec 2019 
\end{DoxyDate}

\doxysubsection{Function Documentation}
\mbox{\Hypertarget{pidController_8h_ad2327b73379de6859aafb872d874273d}\label{pidController_8h_ad2327b73379de6859aafb872d874273d}} 
\index{pidController.h@{pidController.h}!pidHandler@{pidHandler}}
\index{pidHandler@{pidHandler}!pidController.h@{pidController.h}}
\doxysubsubsection{\texorpdfstring{pidHandler()}{pidHandler()}}
{\footnotesize\ttfamily double pid\+Handler (\begin{DoxyParamCaption}\item[{int}]{current\+Position }\end{DoxyParamCaption})}

Função Principal do P\+ID Para Cálculo de Tensão. Rotina Para fazer os cálculos do P\+ID e suas variáveis tal como desvios e erros, retornando o valor de tensao que deve ser aplicado no motor. 

O cálculo nesta função basea-\/se na leitura atual da posição do motor dessa maneira gera um valor de tensão para que atinja o alvo.

\begin{DoxyParams}{Parameters}
{\em current\+Position} & Posicao Corrente \\
\hline
\end{DoxyParams}
\begin{DoxyReturn}{Returns}
Valor de Tensão que deve ser aplicado no Motor 
\end{DoxyReturn}

Definition at line 126 of file pid\+Controller.\+c.

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

\end{DoxyCode}
\mbox{\Hypertarget{pidController_8h_a0a8eecf482506155e3b690c45f4c4e4b}\label{pidController_8h_a0a8eecf482506155e3b690c45f4c4e4b}} 
\index{pidController.h@{pidController.h}!setControlKd@{setControlKd}}
\index{setControlKd@{setControlKd}!pidController.h@{pidController.h}}
\doxysubsubsection{\texorpdfstring{setControlKd()}{setControlKd()}}
{\footnotesize\ttfamily void set\+Control\+Kd (\begin{DoxyParamCaption}\item[{double}]{new\+Kd }\end{DoxyParamCaption})}

Função para setar Kd. Rotina responsável por Setar Kd, valor parte da integral. 

\begin{DoxyParams}{Parameters}
{\em Novo} & KD \\
\hline
\end{DoxyParams}

Definition at line 100 of file pid\+Controller.\+c.

\begin{DoxyCode}{0}
\DoxyCodeLine{100                                \{}
\DoxyCodeLine{101     \textcolor{keywordflow}{if}(\mbox{\hyperlink{helpers_8h_ad72dbcf6d0153db1b8d8a58001feed83}{DEBUG}}) printf(\textcolor{stringliteral}{"[DEBUG] -\/ Starting setControlKd pidController \(\backslash\)n"});}
\DoxyCodeLine{102     \mbox{\hyperlink{pidController_8c_ab032dbb879b584cedb078654339a3a97}{controlKd}} = newKd;}
\DoxyCodeLine{103     printf(\textcolor{stringliteral}{"[INFO] -\/ controlKd Value: \%f \(\backslash\)n"}, \mbox{\hyperlink{pidController_8c_ab032dbb879b584cedb078654339a3a97}{controlKd}});}
\DoxyCodeLine{104 \}}

\end{DoxyCode}
\mbox{\Hypertarget{pidController_8h_a315d3a9847f641c407ef6b32a65fd640}\label{pidController_8h_a315d3a9847f641c407ef6b32a65fd640}} 
\index{pidController.h@{pidController.h}!setControlKi@{setControlKi}}
\index{setControlKi@{setControlKi}!pidController.h@{pidController.h}}
\doxysubsubsection{\texorpdfstring{setControlKi()}{setControlKi()}}
{\footnotesize\ttfamily void set\+Control\+Ki (\begin{DoxyParamCaption}\item[{double}]{new\+Ki }\end{DoxyParamCaption})}

Função para setar Ki. Rotina responsável por setar Ki, valor parte da integral. 

\begin{DoxyParams}{Parameters}
{\em Novo} & KI \\
\hline
\end{DoxyParams}

Definition at line 111 of file pid\+Controller.\+c.

\begin{DoxyCode}{0}
\DoxyCodeLine{111                                \{}
\DoxyCodeLine{112     \textcolor{keywordflow}{if}(\mbox{\hyperlink{helpers_8h_ad72dbcf6d0153db1b8d8a58001feed83}{DEBUG}}) printf(\textcolor{stringliteral}{"[DEBUG] -\/ Starting setControlKi pidController \(\backslash\)n"});}
\DoxyCodeLine{113     \mbox{\hyperlink{pidController_8c_a8467e669549465248016d01cc5f9f0ad}{controlKi}} = newKi;}
\DoxyCodeLine{114     printf(\textcolor{stringliteral}{"[INFO] -\/ controlKi Value: \%f \(\backslash\)n"}, \mbox{\hyperlink{pidController_8c_a8467e669549465248016d01cc5f9f0ad}{controlKi}});}
\DoxyCodeLine{115 \}}

\end{DoxyCode}
\mbox{\Hypertarget{pidController_8h_a8d8cec964229574d5f0af312a00e5935}\label{pidController_8h_a8d8cec964229574d5f0af312a00e5935}} 
\index{pidController.h@{pidController.h}!setControlKp@{setControlKp}}
\index{setControlKp@{setControlKp}!pidController.h@{pidController.h}}
\doxysubsubsection{\texorpdfstring{setControlKp()}{setControlKp()}}
{\footnotesize\ttfamily void set\+Control\+Kp (\begin{DoxyParamCaption}\item[{double}]{new\+Kp }\end{DoxyParamCaption})}

Função para setar Kp. Rotina Repsonsavel por Setar Kp, valor parte da integral. 

\begin{DoxyParams}{Parameters}
{\em Novo} & KP \\
\hline
\end{DoxyParams}

Definition at line 89 of file pid\+Controller.\+c.

\begin{DoxyCode}{0}
\DoxyCodeLine{89                                \{}
\DoxyCodeLine{90     \textcolor{keywordflow}{if}(\mbox{\hyperlink{helpers_8h_ad72dbcf6d0153db1b8d8a58001feed83}{DEBUG}}) printf(\textcolor{stringliteral}{"[DEBUG] -\/ Starting setControlKp pidController \(\backslash\)n"});}
\DoxyCodeLine{91     \mbox{\hyperlink{pidController_8c_add21ccb04e1708df9847b3537c3c160d}{controlKp}} = newKp;}
\DoxyCodeLine{92     printf(\textcolor{stringliteral}{"[INFO] -\/ controlKp Value: \%f \(\backslash\)n"}, \mbox{\hyperlink{pidController_8c_add21ccb04e1708df9847b3537c3c160d}{controlKp}});}
\DoxyCodeLine{93 \}}

\end{DoxyCode}
\mbox{\Hypertarget{pidController_8h_abe99aea2237bf45370f11475aab83cdd}\label{pidController_8h_abe99aea2237bf45370f11475aab83cdd}} 
\index{pidController.h@{pidController.h}!setTarget@{setTarget}}
\index{setTarget@{setTarget}!pidController.h@{pidController.h}}
\doxysubsubsection{\texorpdfstring{setTarget()}{setTarget()}}
{\footnotesize\ttfamily int set\+Target (\begin{DoxyParamCaption}\item[{int}]{new\+Target }\end{DoxyParamCaption})}

Função para setar nova posição. Rotina responsável por setar uma nova posição desejada. É nesta função que são zerados os valores de parte de erros e outras variáveis já calculadas. A nova posição é convertida e armazenada em target\+Location. 

\begin{DoxyParams}{Parameters}
{\em new\+Target} & Nova Posicao \\
\hline
\end{DoxyParams}
\begin{DoxyReturn}{Returns}
Retorna Positivo Caso Consiga Setar Nova Posicao. 
\end{DoxyReturn}

Definition at line 48 of file pid\+Controller.\+c.

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

\end{DoxyCode}
\mbox{\Hypertarget{pidController_8h_aa2a62b6c21f82bd7e19c63e02d2cf01c}\label{pidController_8h_aa2a62b6c21f82bd7e19c63e02d2cf01c}} 
\index{pidController.h@{pidController.h}!turnOffPid@{turnOffPid}}
\index{turnOffPid@{turnOffPid}!pidController.h@{pidController.h}}
\doxysubsubsection{\texorpdfstring{turnOffPid()}{turnOffPid()}}
{\footnotesize\ttfamily void turn\+Off\+Pid (\begin{DoxyParamCaption}{ }\end{DoxyParamCaption})}

Função para desligar o Pid Rotina responsável por desligar O P\+ID. 

\begin{DoxyItemize}
\item \begin{DoxyReturn}{Returns}
Void 
\end{DoxyReturn}

\end{DoxyItemize}

Definition at line 76 of file pid\+Controller.\+c.

\begin{DoxyCode}{0}
\DoxyCodeLine{76                  \{}
\DoxyCodeLine{77     \textcolor{keywordflow}{if}(\mbox{\hyperlink{helpers_8h_ad72dbcf6d0153db1b8d8a58001feed83}{DEBUG}}) printf(\textcolor{stringliteral}{"[DEBUG] -\/ Starting turnOffPidStatus pidController \(\backslash\)n"});}
\DoxyCodeLine{78     \textcolor{keywordflow}{if}(\mbox{\hyperlink{pidController_8c_a11837efa2f154aaa978a9c69a16e88e2}{pidStatus}} == TRUE)\{}
\DoxyCodeLine{79         \textcolor{keywordflow}{if}(\mbox{\hyperlink{helpers_8h_ad72dbcf6d0153db1b8d8a58001feed83}{DEBUG}}) printf(\textcolor{stringliteral}{"[DEBUG] -\/ Setting pidStatus FALSE \(\backslash\)n"});}
\DoxyCodeLine{80         \mbox{\hyperlink{pidController_8c_a11837efa2f154aaa978a9c69a16e88e2}{pidStatus}} = FALSE;}
\DoxyCodeLine{81     \}}
\DoxyCodeLine{82 \}}

\end{DoxyCode}
\mbox{\Hypertarget{pidController_8h_ad44a79f712b96530f491cf5a841c9817}\label{pidController_8h_ad44a79f712b96530f491cf5a841c9817}} 
\index{pidController.h@{pidController.h}!turnOnPid@{turnOnPid}}
\index{turnOnPid@{turnOnPid}!pidController.h@{pidController.h}}
\doxysubsubsection{\texorpdfstring{turnOnPid()}{turnOnPid()}}
{\footnotesize\ttfamily void turn\+On\+Pid (\begin{DoxyParamCaption}{ }\end{DoxyParamCaption})}

Função para ligar o Pid. Rotina responsável Por Ligar O P\+ID. 

\begin{DoxyReturn}{Returns}
Void 
\end{DoxyReturn}

Definition at line 63 of file pid\+Controller.\+c.

\begin{DoxyCode}{0}
\DoxyCodeLine{63                 \{}
\DoxyCodeLine{64     \textcolor{keywordflow}{if}(\mbox{\hyperlink{helpers_8h_ad72dbcf6d0153db1b8d8a58001feed83}{DEBUG}}) printf(\textcolor{stringliteral}{"[DEBUG] -\/ Starting turnOnPidStatus pidController \(\backslash\)n"});}
\DoxyCodeLine{65     \textcolor{keywordflow}{if}(\mbox{\hyperlink{pidController_8c_a11837efa2f154aaa978a9c69a16e88e2}{pidStatus}} == FALSE)\{}
\DoxyCodeLine{66         \textcolor{keywordflow}{if}(\mbox{\hyperlink{helpers_8h_ad72dbcf6d0153db1b8d8a58001feed83}{DEBUG}}) printf(\textcolor{stringliteral}{"[DEBUG] -\/ Setting pidStatus TRUE \(\backslash\)n"});}
\DoxyCodeLine{67         \mbox{\hyperlink{pidController_8c_a11837efa2f154aaa978a9c69a16e88e2}{pidStatus}} = TRUE;}
\DoxyCodeLine{68     \}}
\DoxyCodeLine{69 \}}

\end{DoxyCode}

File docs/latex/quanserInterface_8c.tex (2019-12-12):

\hypertarget{quanserInterface_8c}{}\doxysection{src/quanser\+Interface/quanser\+Interface.c File Reference}
\label{quanserInterface_8c}\index{src/quanserInterface/quanserInterface.c@{src/quanserInterface/quanserInterface.c}}

Funções para funcionamento do Motor, P\+WM e Ponte H.  

{\ttfamily \#include \char`\"{}quanser\+Interface.\+h\char`\"{}}\newline
\doxysubsection*{Functions}
\begin{DoxyCompactItemize}
\item 
int \mbox{\hyperlink{quanserInterface_8c_a72cb6672e7a2002cb3eed86f8d58781f}{handle\+Pwm}} (int dc\+Amount)
\begin{DoxyCompactList}\small\item\em Função para setar P\+WM e habilitar P\+WM e ponte H. Rotina responsável por setar o valor do duty cycle em função do valor de tensão passado por parâmetro. \end{DoxyCompactList}\item 
int \mbox{\hyperlink{quanserInterface_8c_a2cb713f85c500012763209e2ffc0acf7}{qser\+Initializer}} ()
\begin{DoxyCompactList}\small\item\em Função para inicialização do decoder e motor. Rotina responsável pela inicialização do motor e também do decoder. \end{DoxyCompactList}\item 
int \mbox{\hyperlink{quanserInterface_8c_a0cd1c4a8a39f9776767a0a1c843e51f1}{qser\+Break}} ()
\begin{DoxyCompactList}\small\item\em Função responsável por desabilitar a ponte h. Rotina responsável por desabilitar a Ponte H. \end{DoxyCompactList}\item 
int \mbox{\hyperlink{quanserInterface_8c_a0c496c62c73c815a5b92cd2935452dbb}{qser\+Voltage}} (float voltage)
\begin{DoxyCompactList}\small\item\em Função para converter voltagem em duty cycle. Rotina responsável por transformar os valores de tensão em Duty Cycle. \end{DoxyCompactList}\item 
void $\ast$ \mbox{\hyperlink{quanserInterface_8c_aae0d60cf64732012d55de41aa4ed5d75}{joint\+Position\+Limit\+One\+Handler}} ()
\begin{DoxyCompactList}\small\item\em Thread Um de interrupções de fim de curso. Thread responsável por escutar interrupções de fim de curso assim como fazer a pausa do motor e o desligamento do P\+ID. \end{DoxyCompactList}\item 
void $\ast$ \mbox{\hyperlink{quanserInterface_8c_af380e7b0608373355426a5ba9382824c}{joint\+Position\+Limit\+Two\+Handler}} ()
\begin{DoxyCompactList}\small\item\em Thread Dois de interrupções de fim de curso. Thread Reponseavel por escutar interrupcoes de fim de curso assim como fazer a pausa do motor e o desligamento do P\+ID. \end{DoxyCompactList}\item 
void $\ast$ \mbox{\hyperlink{quanserInterface_8c_a6b0fef0560db647615037ae9085ee266}{go\+To\+Target\+Position\+Handler}} ()
\begin{DoxyCompactList}\small\item\em Thread para assegurar troca de posições Thread Responsável por executar a alteração do braço para uma nova posição. \end{DoxyCompactList}\end{DoxyCompactItemize}

\doxysubsection{Detailed Description}
Funções para funcionamento do Motor, P\+WM e Ponte H. 

\begin{DoxyAuthor}{Author}
Rodolfo Viola Carvalho, Gabriel Alexandre Zillmer, Felipe Fuhr Dos Reis 
\end{DoxyAuthor}
\begin{DoxyDate}{Date}
11 Dec 2019 
\end{DoxyDate}

\doxysubsection{Function Documentation}
\mbox{\Hypertarget{quanserInterface_8c_a6b0fef0560db647615037ae9085ee266}\label{quanserInterface_8c_a6b0fef0560db647615037ae9085ee266}} 
\index{quanserInterface.c@{quanserInterface.c}!goToTargetPositionHandler@{goToTargetPositionHandler}}
\index{goToTargetPositionHandler@{goToTargetPositionHandler}!quanserInterface.c@{quanserInterface.c}}
\doxysubsubsection{\texorpdfstring{goToTargetPositionHandler()}{goToTargetPositionHandler()}}
{\footnotesize\ttfamily void$\ast$ go\+To\+Target\+Position\+Handler (\begin{DoxyParamCaption}{ }\end{DoxyParamCaption})}

Thread para assegurar troca de posições Thread Responsável por executar a alteração do braço para uma nova posição. 

Loop Infinito que verifica se o P\+ID está ativo para aplicar as tensão necessárias.

Tempo aguardado para cada rotação é de 10k micro segundos (100 Hz)
\begin{DoxyItemize}
\item \begin{DoxyReturn}{Returns}
Retorna um Ponteiro Para Null 
\end{DoxyReturn}

\end{DoxyItemize}

Definition at line 209 of file quanser\+Interface.\+c.

\begin{DoxyCode}{0}
\DoxyCodeLine{209                                  \{}
\DoxyCodeLine{210     \textcolor{keywordflow}{if}(\mbox{\hyperlink{helpers_8h_ad72dbcf6d0153db1b8d8a58001feed83}{DEBUG}}) printf(\textcolor{stringliteral}{"[DEBUG] -\/ Starting goTo Target Position Handler Thread \(\backslash\)n"});}
\DoxyCodeLine{211     \textcolor{keywordtype}{int} currentPosition = \mbox{\hyperlink{decoderInterface_8c_af5872793a562a54c455d94fef27f3a2b}{readDecoderCounter}}();}
\DoxyCodeLine{212     \textcolor{keywordflow}{while}(TRUE) \{}
\DoxyCodeLine{213         \textcolor{keywordflow}{if}(\mbox{\hyperlink{mainThread_8h_a11837efa2f154aaa978a9c69a16e88e2}{pidStatus}} == TRUE) \{}
\DoxyCodeLine{214             \textcolor{keywordtype}{float} voltage = (float)\mbox{\hyperlink{pidController_8c_ad2327b73379de6859aafb872d874273d}{pidHandler}}(currentPosition);}
\DoxyCodeLine{215             \textcolor{keywordflow}{if}(\mbox{\hyperlink{quanserInterface_8c_a0c496c62c73c815a5b92cd2935452dbb}{qserVoltage}}(voltage) == 0) \{}
\DoxyCodeLine{216                 fprintf(stderr, \textcolor{stringliteral}{"[ERROR] -\/ Error While Trying To Move Motor Position\(\backslash\)n"});}
\DoxyCodeLine{217                 \textcolor{keywordflow}{return} FALSE;}
\DoxyCodeLine{218             \}}
\DoxyCodeLine{219             currentPosition = \mbox{\hyperlink{decoderInterface_8c_af5872793a562a54c455d94fef27f3a2b}{readDecoderCounter}}();}
\DoxyCodeLine{220         \}}
\DoxyCodeLine{221         usleep(10000);}
\DoxyCodeLine{222     \}}
\DoxyCodeLine{223     printf(\textcolor{stringliteral}{"[INFO] -\/ Reached The End goToTargetPositionHandler Thread\(\backslash\)n"});}
\DoxyCodeLine{224     \textcolor{keywordflow}{return} NULL;}
\DoxyCodeLine{225 \}}

\end{DoxyCode}
\mbox{\Hypertarget{quanserInterface_8c_a72cb6672e7a2002cb3eed86f8d58781f}\label{quanserInterface_8c_a72cb6672e7a2002cb3eed86f8d58781f}} 
\index{quanserInterface.c@{quanserInterface.c}!handlePwm@{handlePwm}}
\index{handlePwm@{handlePwm}!quanserInterface.c@{quanserInterface.c}}
\doxysubsubsection{\texorpdfstring{handlePwm()}{handlePwm()}}
{\footnotesize\ttfamily int handle\+Pwm (\begin{DoxyParamCaption}\item[{int}]{dc\+Amount }\end{DoxyParamCaption})}

Função para setar P\+WM e habilitar P\+WM e ponte H. Rotina responsável por setar o valor do duty cycle em função do valor de tensão passado por parâmetro. 

Também é papel desta função de habilitar o pino de enable ponte h e setar o período do P\+WM,

\begin{DoxyParams}{Parameters}
{\em dc\+Amount} & Valor em nano segundos do Duty Cycle a ser aplicado \\
\hline
\end{DoxyParams}
\begin{DoxyReturn}{Returns}
Retorna Positivo Caso Consiga Setar um novo Duty Cycle. 
\end{DoxyReturn}

Definition at line 35 of file quanser\+Interface.\+c.

\begin{DoxyCode}{0}
\DoxyCodeLine{35                             \{}
\DoxyCodeLine{36     \textcolor{keywordflow}{if}(\mbox{\hyperlink{helpers_8h_ad72dbcf6d0153db1b8d8a58001feed83}{DEBUG}}) printf(\textcolor{stringliteral}{"[DEBUG] -\/ Starting handlePwm\(\backslash\)n"});}
\DoxyCodeLine{37     \textcolor{keywordflow}{if}(\mbox{\hyperlink{helpers_8h_afb786d718c78c0731bb746dd2bdb9372}{IS\_RUNNING\_LOCAL}}) \textcolor{keywordflow}{return} TRUE;}
\DoxyCodeLine{38     \textcolor{keywordtype}{char} dataFull[20];}
\DoxyCodeLine{39     snprintf(dataFull, \textcolor{keyword}{sizeof}(dataFull), \textcolor{stringliteral}{"\%d\(\backslash\)n"}, dcAmount);}
\DoxyCodeLine{40     \textcolor{keywordflow}{if}(\mbox{\hyperlink{helpers_8c_a11518359bc1427b7f3fc6f3ce336db15}{writeHandler}}(\textcolor{stringliteral}{"/sys/class/gpio/gpio38/value"}, \textcolor{stringliteral}{"1"}) < 0) \textcolor{keywordflow}{return} FALSE;}
\DoxyCodeLine{41     \textcolor{keywordflow}{if}(\mbox{\hyperlink{helpers_8c_a11518359bc1427b7f3fc6f3ce336db15}{writeHandler}}(\textcolor{stringliteral}{"/sys/class/pwm/pwmchip0/pwm1/enable"}, \textcolor{stringliteral}{"1"}) < 0) \textcolor{keywordflow}{return} FALSE;}
\DoxyCodeLine{42     \textcolor{keywordflow}{if}(\mbox{\hyperlink{helpers_8c_a11518359bc1427b7f3fc6f3ce336db15}{writeHandler}}(\textcolor{stringliteral}{"/sys/class/pwm/pwmchip0/device/pwm\_period"}, \mbox{\hyperlink{quanserInterface_8h_aacaca0988244bd3a888ca5befa89f44b}{PWM\_PERIOD}}) < 0) \textcolor{keywordflow}{return} FALSE;}
\DoxyCodeLine{43     \textcolor{keywordflow}{if}(\mbox{\hyperlink{helpers_8c_a11518359bc1427b7f3fc6f3ce336db15}{writeHandler}}(\textcolor{stringliteral}{"/sys/class/pwm/pwmchip0/pwm1/duty\_cycle"}, dataFull) < 0) \textcolor{keywordflow}{return} FALSE;}
\DoxyCodeLine{44     \textcolor{keywordflow}{if}(\mbox{\hyperlink{helpers_8h_ad72dbcf6d0153db1b8d8a58001feed83}{DEBUG}}) printf(\textcolor{stringliteral}{"[DEBUG] -\/ Finishing handlePwm"});}
\DoxyCodeLine{45     \textcolor{keywordflow}{return} TRUE;}
\DoxyCodeLine{46 \}}

\end{DoxyCode}
\mbox{\Hypertarget{quanserInterface_8c_aae0d60cf64732012d55de41aa4ed5d75}\label{quanserInterface_8c_aae0d60cf64732012d55de41aa4ed5d75}} 
\index{quanserInterface.c@{quanserInterface.c}!jointPositionLimitOneHandler@{jointPositionLimitOneHandler}}
\index{jointPositionLimitOneHandler@{jointPositionLimitOneHandler}!quanserInterface.c@{quanserInterface.c}}
\doxysubsubsection{\texorpdfstring{jointPositionLimitOneHandler()}{jointPositionLimitOneHandler()}}
{\footnotesize\ttfamily void$\ast$ joint\+Position\+Limit\+One\+Handler (\begin{DoxyParamCaption}{ }\end{DoxyParamCaption})}

Thread Um de interrupções de fim de curso. Thread responsável por escutar interrupções de fim de curso assim como fazer a pausa do motor e o desligamento do P\+ID. 

Interrupções sensíveis aos níveis de borda de subida e descida

\begin{DoxyReturn}{Returns}
Retorna um Ponteiro Para Null 
\end{DoxyReturn}

Definition at line 109 of file quanser\+Interface.\+c.

\begin{DoxyCode}{0}
\DoxyCodeLine{109                                      \{}
\DoxyCodeLine{110     \textcolor{keywordflow}{if}(\mbox{\hyperlink{helpers_8h_afb786d718c78c0731bb746dd2bdb9372}{IS\_RUNNING\_LOCAL}}) \textcolor{keywordflow}{return} 0;}
\DoxyCodeLine{111     \textcolor{keywordflow}{if}(\mbox{\hyperlink{helpers_8h_ad72dbcf6d0153db1b8d8a58001feed83}{DEBUG}}) printf(\textcolor{stringliteral}{"[DEBUG] -\/ Starting Joint Position Limiter Handler Thread \(\backslash\)n"});}
\DoxyCodeLine{112     \textcolor{keywordtype}{char} rootPathLimiterOneValue[100] = \textcolor{stringliteral}{"/sys/class/gpio/gpio6/value"};}
\DoxyCodeLine{113     \textcolor{keywordtype}{char} rootPathLimiterOneEdge[100] = \textcolor{stringliteral}{"/sys/class/gpio/gpio6/edge"};}
\DoxyCodeLine{114 }
\DoxyCodeLine{115     \textcolor{keywordtype}{unsigned} \textcolor{keywordtype}{char} dataOne;}
\DoxyCodeLine{116     \textcolor{keyword}{struct }pollfd pollFileHandlerOne;}
\DoxyCodeLine{117 }
\DoxyCodeLine{118     \textcolor{keywordflow}{if}(\mbox{\hyperlink{helpers_8h_ad72dbcf6d0153db1b8d8a58001feed83}{DEBUG}}) printf(\textcolor{stringliteral}{"[DEBUG] -\/ JPL Opening First File GPIO 6\(\backslash\)n"});}
\DoxyCodeLine{119     \textcolor{keywordflow}{if}((pollFileHandlerOne.fd = open(rootPathLimiterOneValue, O\_RDONLY)) < 0) \{}
\DoxyCodeLine{120         fprintf(stderr, \textcolor{stringliteral}{"[ERROR] -\/ Joint Position Limiter One Open File Descriptor Error \%s.\(\backslash\)n"}, rootPathLimiterOneValue);}
\DoxyCodeLine{121         exit(11);}
\DoxyCodeLine{122     \}}
\DoxyCodeLine{123 }
\DoxyCodeLine{124     read(pollFileHandlerOne.fd,\&dataOne,1);}
\DoxyCodeLine{125 }
\DoxyCodeLine{126     \textcolor{keywordflow}{if}(\mbox{\hyperlink{helpers_8h_ad72dbcf6d0153db1b8d8a58001feed83}{DEBUG}}) printf(\textcolor{stringliteral}{"[DEBUG] -\/ Starting Joint Position Limiter Handler While \(\backslash\)n"});}
\DoxyCodeLine{127     \textcolor{keywordtype}{int} shouldNeverStop = TRUE;}
\DoxyCodeLine{128     \textcolor{keywordflow}{while}(shouldNeverStop) \{}
\DoxyCodeLine{129         \textcolor{keywordflow}{if}(\mbox{\hyperlink{helpers_8h_ad72dbcf6d0153db1b8d8a58001feed83}{DEBUG}}) printf(\textcolor{stringliteral}{"[DEBUG] -\/ Checking Joint Position Limiter \(\backslash\)n"});}
\DoxyCodeLine{130         pollFileHandlerOne.events = POLLPRI;}
\DoxyCodeLine{131         \mbox{\hyperlink{helpers_8c_a11518359bc1427b7f3fc6f3ce336db15}{writeHandler}}(rootPathLimiterOneEdge,\textcolor{stringliteral}{"both"});}
\DoxyCodeLine{132         poll(\&pollFileHandlerOne,1,-\/1);}
\DoxyCodeLine{133         lseek(pollFileHandlerOne.fd,0,SEEK\_SET);}
\DoxyCodeLine{134         \textcolor{keywordflow}{if}(\mbox{\hyperlink{helpers_8h_ad72dbcf6d0153db1b8d8a58001feed83}{DEBUG}}) printf(\textcolor{stringliteral}{"[DEBUG] -\/ JPL Reading First File GPIO 0\(\backslash\)n"});}
\DoxyCodeLine{135         \textcolor{keywordflow}{if}(read(pollFileHandlerOne.fd, \&dataOne, 1) < 0) \{}
\DoxyCodeLine{136             fprintf(stderr, \textcolor{stringliteral}{"[ERROR] -\/ JPL One Reading Error \%s\(\backslash\)n\(\backslash\)n"}, rootPathLimiterOneValue);}
\DoxyCodeLine{137             exit(2);}
\DoxyCodeLine{138         \}}
\DoxyCodeLine{139         \textcolor{keywordflow}{if}(\mbox{\hyperlink{helpers_8h_ad72dbcf6d0153db1b8d8a58001feed83}{DEBUG}}) printf(\textcolor{stringliteral}{"[DEBUG] -\/ JPL Testing For End\(\backslash\)n"});}
\DoxyCodeLine{140         \textcolor{keywordflow}{if}(dataOne == JPL\_REACHED) \{}
\DoxyCodeLine{141             printf(\textcolor{stringliteral}{"[INFO] -\/ JPL ONE Reached End \(\backslash\)n\(\backslash\)n"});}
\DoxyCodeLine{142             \mbox{\hyperlink{quanserInterface_8c_a0cd1c4a8a39f9776767a0a1c843e51f1}{qserBreak}}();}
\DoxyCodeLine{143             \mbox{\hyperlink{pidController_8c_aa2a62b6c21f82bd7e19c63e02d2cf01c}{turnOffPid}}();}
\DoxyCodeLine{144         \}}
\DoxyCodeLine{145         \mbox{\hyperlink{mainThread_8c_a1516fc9ce70a57d79877afa8ef7921f7}{JPL\_REACHED\_STATUS\_ONE}} = dataOne;}
\DoxyCodeLine{146 }
\DoxyCodeLine{147     \}}
\DoxyCodeLine{148     \textcolor{keywordflow}{return} NULL;}
\DoxyCodeLine{149 \}}

\end{DoxyCode}
\mbox{\Hypertarget{quanserInterface_8c_af380e7b0608373355426a5ba9382824c}\label{quanserInterface_8c_af380e7b0608373355426a5ba9382824c}} 
\index{quanserInterface.c@{quanserInterface.c}!jointPositionLimitTwoHandler@{jointPositionLimitTwoHandler}}
\index{jointPositionLimitTwoHandler@{jointPositionLimitTwoHandler}!quanserInterface.c@{quanserInterface.c}}
\doxysubsubsection{\texorpdfstring{jointPositionLimitTwoHandler()}{jointPositionLimitTwoHandler()}}
{\footnotesize\ttfamily void$\ast$ joint\+Position\+Limit\+Two\+Handler (\begin{DoxyParamCaption}{ }\end{DoxyParamCaption})}

Thread Dois de interrupções de fim de curso. Thread Reponseavel por escutar interrupcoes de fim de curso assim como fazer a pausa do motor e o desligamento do P\+ID. 

Interrupções sensíveis aos níveis de borda de subida e descida

\begin{DoxyReturn}{Returns}
Retorna um Ponteiro Para Null 
\end{DoxyReturn}

Definition at line 158 of file quanser\+Interface.\+c.

\begin{DoxyCode}{0}
\DoxyCodeLine{158                                      \{}
\DoxyCodeLine{159     \textcolor{keywordflow}{if}(\mbox{\hyperlink{helpers_8h_afb786d718c78c0731bb746dd2bdb9372}{IS\_RUNNING\_LOCAL}}) \textcolor{keywordflow}{return} 0;}
\DoxyCodeLine{160     \textcolor{keywordflow}{if}(\mbox{\hyperlink{helpers_8h_ad72dbcf6d0153db1b8d8a58001feed83}{DEBUG}}) printf(\textcolor{stringliteral}{"[DEBUG] -\/ Starting Joint Position Limiter Handler Thread \(\backslash\)n"});}
\DoxyCodeLine{161     \textcolor{keywordtype}{char} rootPathLimiterTwoValue[100] = \textcolor{stringliteral}{"/sys/class/gpio/gpio0/value"};}
\DoxyCodeLine{162     \textcolor{keywordtype}{char} rootPathLimiterTwoEdge[100] = \textcolor{stringliteral}{"/sys/class/gpio/gpio0/edge"};}
\DoxyCodeLine{163 }
\DoxyCodeLine{164     \textcolor{keywordtype}{unsigned} \textcolor{keywordtype}{char} dataTwo;}
\DoxyCodeLine{165     \textcolor{keyword}{struct }pollfd pollFileHandlerTwo;}
\DoxyCodeLine{166 }
\DoxyCodeLine{167     \textcolor{keywordflow}{if}(\mbox{\hyperlink{helpers_8h_ad72dbcf6d0153db1b8d8a58001feed83}{DEBUG}}) printf(\textcolor{stringliteral}{"[DEBUG] -\/ JPL Opening First File GPIO 6\(\backslash\)n"});}
\DoxyCodeLine{168     \textcolor{keywordflow}{if}((pollFileHandlerTwo.fd = open(rootPathLimiterTwoValue, O\_RDONLY)) < 0) \{}
\DoxyCodeLine{169         fprintf(stderr, \textcolor{stringliteral}{"[ERROR] -\/ Joint Position Limiter Two Open File Descriptor Error \%s.\(\backslash\)n"}, rootPathLimiterTwoValue);}
\DoxyCodeLine{170         exit(11);}
\DoxyCodeLine{171     \}}
\DoxyCodeLine{172 }
\DoxyCodeLine{173     read(pollFileHandlerTwo.fd, \&dataTwo, 1);}
\DoxyCodeLine{174 }
\DoxyCodeLine{175     \textcolor{keywordflow}{if}(\mbox{\hyperlink{helpers_8h_ad72dbcf6d0153db1b8d8a58001feed83}{DEBUG}}) printf(\textcolor{stringliteral}{"[DEBUG] -\/ Starting Joint Position Limiter Handler While \(\backslash\)n"});}
\DoxyCodeLine{176     \textcolor{keywordtype}{int} shouldNeverStop = TRUE;}
\DoxyCodeLine{177     \textcolor{keywordflow}{while}(shouldNeverStop) \{}
\DoxyCodeLine{178         \textcolor{keywordflow}{if}(\mbox{\hyperlink{helpers_8h_ad72dbcf6d0153db1b8d8a58001feed83}{DEBUG}}) printf(\textcolor{stringliteral}{"[DEBUG] -\/ Checking Joint Position Limiter \(\backslash\)n"});}
\DoxyCodeLine{179         pollFileHandlerTwo.events = POLLPRI;}
\DoxyCodeLine{180         \mbox{\hyperlink{helpers_8c_a11518359bc1427b7f3fc6f3ce336db15}{writeHandler}}(rootPathLimiterTwoEdge,\textcolor{stringliteral}{"both"});}
\DoxyCodeLine{181         poll(\&pollFileHandlerTwo, 1, -\/1);}
\DoxyCodeLine{182         lseek(pollFileHandlerTwo.fd, 0, SEEK\_SET);}
\DoxyCodeLine{183         \textcolor{keywordflow}{if}(\mbox{\hyperlink{helpers_8h_ad72dbcf6d0153db1b8d8a58001feed83}{DEBUG}}) printf(\textcolor{stringliteral}{"[DEBUG] -\/ JPL Reading First File GPIO 0\(\backslash\)n"});}
\DoxyCodeLine{184         \textcolor{keywordflow}{if}(read(pollFileHandlerTwo.fd, \&dataTwo, 1) < 0) \{}
\DoxyCodeLine{185             fprintf(stderr, \textcolor{stringliteral}{"[ERROR] -\/ JPL Two Reading Error \%s\(\backslash\)n\(\backslash\)n"}, rootPathLimiterTwoValue);}
\DoxyCodeLine{186             exit(2);}
\DoxyCodeLine{187         \}}
\DoxyCodeLine{188         \textcolor{keywordflow}{if}(\mbox{\hyperlink{helpers_8h_ad72dbcf6d0153db1b8d8a58001feed83}{DEBUG}}) printf(\textcolor{stringliteral}{"[DEBUG] -\/ JPL Testing For End\(\backslash\)n"});}
\DoxyCodeLine{189         \textcolor{keywordflow}{if}(dataTwo == JPL\_REACHED) \{}
\DoxyCodeLine{190             printf(\textcolor{stringliteral}{"[INFO] -\/ JPL TWO Reached End \(\backslash\)n\(\backslash\)n"});}
\DoxyCodeLine{191             \mbox{\hyperlink{quanserInterface_8c_a0cd1c4a8a39f9776767a0a1c843e51f1}{qserBreak}}();}
\DoxyCodeLine{192             \mbox{\hyperlink{pidController_8c_aa2a62b6c21f82bd7e19c63e02d2cf01c}{turnOffPid}}();}
\DoxyCodeLine{193         \}}
\DoxyCodeLine{194         \mbox{\hyperlink{mainThread_8c_aa084c4495d7058b83b56b41864c10846}{JPL\_REACHED\_STATUS\_TWO}} = dataTwo;}
\DoxyCodeLine{195     \}}
\DoxyCodeLine{196     \textcolor{keywordflow}{return} NULL;}
\DoxyCodeLine{197 \}}

\end{DoxyCode}
\mbox{\Hypertarget{quanserInterface_8c_a0cd1c4a8a39f9776767a0a1c843e51f1}\label{quanserInterface_8c_a0cd1c4a8a39f9776767a0a1c843e51f1}} 
\index{quanserInterface.c@{quanserInterface.c}!qserBreak@{qserBreak}}
\index{qserBreak@{qserBreak}!quanserInterface.c@{quanserInterface.c}}
\doxysubsubsection{\texorpdfstring{qserBreak()}{qserBreak()}}
{\footnotesize\ttfamily int qser\+Break (\begin{DoxyParamCaption}{ }\end{DoxyParamCaption})}

Função responsável por desabilitar a ponte h. Rotina responsável por desabilitar a Ponte H. 

\begin{DoxyReturn}{Returns}
Retorna Positivo Caso Consiga Desabilitar. 
\end{DoxyReturn}

Definition at line 74 of file quanser\+Interface.\+c.

\begin{DoxyCode}{0}
\DoxyCodeLine{74                 \{}
\DoxyCodeLine{75     \textcolor{keywordflow}{if}(\mbox{\hyperlink{helpers_8h_ad72dbcf6d0153db1b8d8a58001feed83}{DEBUG}}) printf(\textcolor{stringliteral}{"[DEBUG] -\/ Starting qserBreak\(\backslash\)n"});}
\DoxyCodeLine{76     \textcolor{keywordflow}{if}(\mbox{\hyperlink{helpers_8h_afb786d718c78c0731bb746dd2bdb9372}{IS\_RUNNING\_LOCAL}}) \textcolor{keywordflow}{return} TRUE;}
\DoxyCodeLine{77     \textcolor{keywordflow}{if}(\mbox{\hyperlink{helpers_8c_a11518359bc1427b7f3fc6f3ce336db15}{writeHandler}}(\textcolor{stringliteral}{"/sys/class/gpio/gpio38/value"}, \textcolor{stringliteral}{"0"}) < 0) \{}
\DoxyCodeLine{78         printf(\textcolor{stringliteral}{"[INFO] -\/ Error Writing qserBreak File Value to Zero"});}
\DoxyCodeLine{79         \textcolor{keywordflow}{return} FALSE;}
\DoxyCodeLine{80     \}}
\DoxyCodeLine{81     \textcolor{keywordflow}{if}(\mbox{\hyperlink{helpers_8h_ad72dbcf6d0153db1b8d8a58001feed83}{DEBUG}}) printf(\textcolor{stringliteral}{"[DEBUG] -\/ Finishing qserBreak\(\backslash\)n"});}
\DoxyCodeLine{82     \textcolor{keywordflow}{return} TRUE;}
\DoxyCodeLine{83 \}}

\end{DoxyCode}
\mbox{\Hypertarget{quanserInterface_8c_a2cb713f85c500012763209e2ffc0acf7}\label{quanserInterface_8c_a2cb713f85c500012763209e2ffc0acf7}} 
\index{quanserInterface.c@{quanserInterface.c}!qserInitializer@{qserInitializer}}
\index{qserInitializer@{qserInitializer}!quanserInterface.c@{quanserInterface.c}}
\doxysubsubsection{\texorpdfstring{qserInitializer()}{qserInitializer()}}
{\footnotesize\ttfamily int qser\+Initializer (\begin{DoxyParamCaption}{ }\end{DoxyParamCaption})}

Função para inicialização do decoder e motor. Rotina responsável pela inicialização do motor e também do decoder. 

A princípal função é garantir que os P\+WM, Ponte H, Decoder estão aptos a funcionarem.

\begin{DoxyReturn}{Returns}
Retorna Positivo Caso Consiga inicializar. 
\end{DoxyReturn}

Definition at line 56 of file quanser\+Interface.\+c.

\begin{DoxyCode}{0}
\DoxyCodeLine{56                       \{}
\DoxyCodeLine{57     \textcolor{keywordflow}{if}(\mbox{\hyperlink{helpers_8h_ad72dbcf6d0153db1b8d8a58001feed83}{DEBUG}}) printf(\textcolor{stringliteral}{"[INFO] -\/ Initializing Qser \(\backslash\)n"});}
\DoxyCodeLine{58     \textcolor{keywordtype}{int} initialPwaValue = 0;}
\DoxyCodeLine{59     \textcolor{keywordflow}{if}(\mbox{\hyperlink{quanserInterface_8c_a72cb6672e7a2002cb3eed86f8d58781f}{handlePwm}}(initialPwaValue) ==  FALSE)\{}
\DoxyCodeLine{60         fprintf(stderr, \textcolor{stringliteral}{"[ERROR] -\/ Error While Trying To Set PWM Initialization\(\backslash\)n"});}
\DoxyCodeLine{61         exit(0);}
\DoxyCodeLine{62     \}}
\DoxyCodeLine{63     \mbox{\hyperlink{quanserInterface_8c_a0cd1c4a8a39f9776767a0a1c843e51f1}{qserBreak}}();}
\DoxyCodeLine{64     \mbox{\hyperlink{decoderInterface_8c_aa643b06f53912de8c90b619803eb27a6}{decoderInitializer}}(\mbox{\hyperlink{decoderInterface_8h_a677a5a2cb49ba023b28f16a3c0d38b0e}{SPI\_DEFAULT\_SPEED}});}
\DoxyCodeLine{65     \mbox{\hyperlink{decoderInterface_8c_a82fe1a26c4a03de6dc52798635d4ca27}{clearDecoder}}();}
\DoxyCodeLine{66     \textcolor{keywordflow}{return} TRUE;}
\DoxyCodeLine{67 \}}

\end{DoxyCode}
\mbox{\Hypertarget{quanserInterface_8c_a0c496c62c73c815a5b92cd2935452dbb}\label{quanserInterface_8c_a0c496c62c73c815a5b92cd2935452dbb}} 
\index{quanserInterface.c@{quanserInterface.c}!qserVoltage@{qserVoltage}}
\index{qserVoltage@{qserVoltage}!quanserInterface.c@{quanserInterface.c}}
\doxysubsubsection{\texorpdfstring{qserVoltage()}{qserVoltage()}}
{\footnotesize\ttfamily int qser\+Voltage (\begin{DoxyParamCaption}\item[{float}]{voltage }\end{DoxyParamCaption})}

Função para converter voltagem em duty cycle. Rotina responsável por transformar os valores de tensão em Duty Cycle. 

Esse função tem como objetivo transformar um valor de tensão em um valor correspondente ao percentual de 0 a 100\% do duty cycle

\begin{DoxyParams}{Parameters}
{\em voltage} & Valor da voltagem a ser aplicada no Motor \\
\hline
\end{DoxyParams}
\begin{DoxyReturn}{Returns}
Retorna o Status 1 Caso Consiga Fazer A Alteracao do Duty Cycle 
\end{DoxyReturn}

Definition at line 94 of file quanser\+Interface.\+c.

\begin{DoxyCode}{0}
\DoxyCodeLine{94                                \{}
\DoxyCodeLine{95     \textcolor{keywordflow}{if}(\mbox{\hyperlink{helpers_8h_ad72dbcf6d0153db1b8d8a58001feed83}{DEBUG}}) printf(\textcolor{stringliteral}{"[DEBUG] -\/ Starting qserVoltage\(\backslash\)n"});}
\DoxyCodeLine{96     \textcolor{keywordtype}{float} dcAmount = (( voltage + \mbox{\hyperlink{quanserInterface_8h_a85d3bb9e37fcff0e990ccd0ecb50f169}{QSER\_VOLTAGE}} ) / ( 2 * \mbox{\hyperlink{quanserInterface_8h_a85d3bb9e37fcff0e990ccd0ecb50f169}{QSER\_VOLTAGE}} )) * atof(\mbox{\hyperlink{quanserInterface_8h_aacaca0988244bd3a888ca5befa89f44b}{PWM\_PERIOD}});}
\DoxyCodeLine{97     \textcolor{keywordflow}{if}(\mbox{\hyperlink{helpers_8h_ad72dbcf6d0153db1b8d8a58001feed83}{DEBUG}}) printf(\textcolor{stringliteral}{"[DEBUG] -\/ Finishing qserVoltage\(\backslash\)n"});}
\DoxyCodeLine{98     \textcolor{keywordflow}{return} \mbox{\hyperlink{quanserInterface_8c_a72cb6672e7a2002cb3eed86f8d58781f}{handlePwm}}((\textcolor{keywordtype}{int})dcAmount);}
\DoxyCodeLine{99 \}}

\end{DoxyCode}

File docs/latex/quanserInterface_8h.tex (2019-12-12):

\hypertarget{quanserInterface_8h}{}\doxysection{src/quanser\+Interface/quanser\+Interface.h File Reference}
\label{quanserInterface_8h}\index{src/quanserInterface/quanserInterface.h@{src/quanserInterface/quanserInterface.h}}

Arquivo de cabeçalho da interface do quanser.  

{\ttfamily \#include $<$stdio.\+h$>$}\newline
{\ttfamily \#include $<$poll.\+h$>$}\newline
{\ttfamily \#include $<$fcntl.\+h$>$}\newline
{\ttfamily \#include $<$unistd.\+h$>$}\newline
{\ttfamily \#include \char`\"{}../helpers/helpers.\+h\char`\"{}}\newline
{\ttfamily \#include \char`\"{}../pid\+Controller/pid\+Controller.\+h\char`\"{}}\newline
{\ttfamily \#include \char`\"{}../decoder\+Interface/decoder\+Interface.\+h\char`\"{}}\newline
\doxysubsection*{Macros}
\begin{DoxyCompactItemize}
\item 
\mbox{\Hypertarget{quanserInterface_8h_aacaca0988244bd3a888ca5befa89f44b}\label{quanserInterface_8h_aacaca0988244bd3a888ca5befa89f44b}} 
\#define \mbox{\hyperlink{quanserInterface_8h_aacaca0988244bd3a888ca5befa89f44b}{P\+W\+M\+\_\+\+P\+E\+R\+I\+OD}}~\char`\"{}1000000\char`\"{}
\begin{DoxyCompactList}\small\item\em Define o Período do P\+WM. \end{DoxyCompactList}\item 
\mbox{\Hypertarget{quanserInterface_8h_a85d3bb9e37fcff0e990ccd0ecb50f169}\label{quanserInterface_8h_a85d3bb9e37fcff0e990ccd0ecb50f169}} 
\#define \mbox{\hyperlink{quanserInterface_8h_a85d3bb9e37fcff0e990ccd0ecb50f169}{Q\+S\+E\+R\+\_\+\+V\+O\+L\+T\+A\+GE}}~27.\+0
\begin{DoxyCompactList}\small\item\em Define Valor de Tensão Máxima. \end{DoxyCompactList}\item 
\mbox{\Hypertarget{quanserInterface_8h_a4e111c8fe62388ff42a9878355034406}\label{quanserInterface_8h_a4e111c8fe62388ff42a9878355034406}} 
\#define \mbox{\hyperlink{quanserInterface_8h_a4e111c8fe62388ff42a9878355034406}{M\+O\+T\+O\+R\+\_\+\+R\+E\+V\+O\+L\+U\+T\+I\+O\+NS}}~4096
\begin{DoxyCompactList}\small\item\em Resolucão do Enconder Definida no Datasheet. \end{DoxyCompactList}\item 
\mbox{\Hypertarget{quanserInterface_8h_af1751c498e9ec2fe3c4e7b1aa7e85ef0}\label{quanserInterface_8h_af1751c498e9ec2fe3c4e7b1aa7e85ef0}} 
\#define \mbox{\hyperlink{quanserInterface_8h_af1751c498e9ec2fe3c4e7b1aa7e85ef0}{M\+O\+T\+O\+R\+\_\+\+P\+U\+L\+S\+ES}}~1024
\begin{DoxyCompactList}\small\item\em Pulsos por Rotacão Definida no Datasheet. \end{DoxyCompactList}\item 
\mbox{\Hypertarget{quanserInterface_8h_aee0960e87ad9e83a0d8648502561f477}\label{quanserInterface_8h_aee0960e87ad9e83a0d8648502561f477}} 
\#define {\bfseries J\+P\+L\+\_\+\+R\+E\+A\+C\+H\+ED}~\textquotesingle{}0\textquotesingle{}
\item 
\mbox{\Hypertarget{quanserInterface_8h_a44ced238885c3a18dbc6b8475d6aabdd}\label{quanserInterface_8h_a44ced238885c3a18dbc6b8475d6aabdd}} 
\#define {\bfseries J\+P\+L\+\_\+\+U\+N\+R\+E\+A\+C\+H\+ED}~\textquotesingle{}1\textquotesingle{}
\end{DoxyCompactItemize}
\doxysubsection*{Functions}
\begin{DoxyCompactItemize}
\item 
int \mbox{\hyperlink{quanserInterface_8h_a72cb6672e7a2002cb3eed86f8d58781f}{handle\+Pwm}} (int dc\+Amount)
\begin{DoxyCompactList}\small\item\em Função para setar P\+WM e habilitar P\+WM e ponte H. Rotina responsável por setar o valor do duty cycle em função do valor de tensão passado por parâmetro. \end{DoxyCompactList}\item 
int \mbox{\hyperlink{quanserInterface_8h_a2cb713f85c500012763209e2ffc0acf7}{qser\+Initializer}} ()
\begin{DoxyCompactList}\small\item\em Função para inicialização do decoder e motor. Rotina responsável pela inicialização do motor e também do decoder. \end{DoxyCompactList}\item 
int \mbox{\hyperlink{quanserInterface_8h_a0cd1c4a8a39f9776767a0a1c843e51f1}{qser\+Break}} ()
\begin{DoxyCompactList}\small\item\em Função responsável por desabilitar a ponte h. Rotina responsável por desabilitar a Ponte H. \end{DoxyCompactList}\item 
int \mbox{\hyperlink{quanserInterface_8h_a0c496c62c73c815a5b92cd2935452dbb}{qser\+Voltage}} (float voltage)
\begin{DoxyCompactList}\small\item\em Função para converter voltagem em duty cycle. Rotina responsável por transformar os valores de tensão em Duty Cycle. \end{DoxyCompactList}\item 
void $\ast$ \mbox{\hyperlink{quanserInterface_8h_aae0d60cf64732012d55de41aa4ed5d75}{joint\+Position\+Limit\+One\+Handler}} ()
\begin{DoxyCompactList}\small\item\em Thread Um de interrupções de fim de curso. Thread responsável por escutar interrupções de fim de curso assim como fazer a pausa do motor e o desligamento do P\+ID. \end{DoxyCompactList}\item 
void $\ast$ \mbox{\hyperlink{quanserInterface_8h_af380e7b0608373355426a5ba9382824c}{joint\+Position\+Limit\+Two\+Handler}} ()
\begin{DoxyCompactList}\small\item\em Thread Dois de interrupções de fim de curso. Thread Reponseavel por escutar interrupcoes de fim de curso assim como fazer a pausa do motor e o desligamento do P\+ID. \end{DoxyCompactList}\item 
void $\ast$ \mbox{\hyperlink{quanserInterface_8h_a6b0fef0560db647615037ae9085ee266}{go\+To\+Target\+Position\+Handler}} ()
\begin{DoxyCompactList}\small\item\em Thread para assegurar troca de posições Thread Responsável por executar a alteração do braço para uma nova posição. \end{DoxyCompactList}\end{DoxyCompactItemize}
\doxysubsection*{Variables}
\begin{DoxyCompactItemize}
\item 
\mbox{\Hypertarget{quanserInterface_8h_a1516fc9ce70a57d79877afa8ef7921f7}\label{quanserInterface_8h_a1516fc9ce70a57d79877afa8ef7921f7}} 
int \mbox{\hyperlink{quanserInterface_8h_a1516fc9ce70a57d79877afa8ef7921f7}{J\+P\+L\+\_\+\+R\+E\+A\+C\+H\+E\+D\+\_\+\+S\+T\+A\+T\+U\+S\+\_\+\+O\+NE}}
\begin{DoxyCompactList}\small\item\em Status do final de curso um. \end{DoxyCompactList}\item 
\mbox{\Hypertarget{quanserInterface_8h_aa084c4495d7058b83b56b41864c10846}\label{quanserInterface_8h_aa084c4495d7058b83b56b41864c10846}} 
int \mbox{\hyperlink{quanserInterface_8h_aa084c4495d7058b83b56b41864c10846}{J\+P\+L\+\_\+\+R\+E\+A\+C\+H\+E\+D\+\_\+\+S\+T\+A\+T\+U\+S\+\_\+\+T\+WO}}
\begin{DoxyCompactList}\small\item\em Status do final de curso dois. \end{DoxyCompactList}\item 
\mbox{\Hypertarget{quanserInterface_8h_a11837efa2f154aaa978a9c69a16e88e2}\label{quanserInterface_8h_a11837efa2f154aaa978a9c69a16e88e2}} 
int \mbox{\hyperlink{quanserInterface_8h_a11837efa2f154aaa978a9c69a16e88e2}{pid\+Status}}
\begin{DoxyCompactList}\small\item\em Define o Status do P\+ID. \end{DoxyCompactList}\end{DoxyCompactItemize}

\doxysubsection{Detailed Description}
Arquivo de cabeçalho da interface do quanser. 

\begin{DoxyAuthor}{Author}
Rodolfo Viola Carvalho, Gabriel Alexandre Zillmer, Felipe Fuhr Dos Reis 
\end{DoxyAuthor}
\begin{DoxyDate}{Date}
11 Dec 2019 
\end{DoxyDate}

\doxysubsection{Function Documentation}
\mbox{\Hypertarget{quanserInterface_8h_a6b0fef0560db647615037ae9085ee266}\label{quanserInterface_8h_a6b0fef0560db647615037ae9085ee266}} 
\index{quanserInterface.h@{quanserInterface.h}!goToTargetPositionHandler@{goToTargetPositionHandler}}
\index{goToTargetPositionHandler@{goToTargetPositionHandler}!quanserInterface.h@{quanserInterface.h}}
\doxysubsubsection{\texorpdfstring{goToTargetPositionHandler()}{goToTargetPositionHandler()}}
{\footnotesize\ttfamily void$\ast$ go\+To\+Target\+Position\+Handler (\begin{DoxyParamCaption}{ }\end{DoxyParamCaption})}

Thread para assegurar troca de posições Thread Responsável por executar a alteração do braço para uma nova posição. 

Loop Infinito que verifica se o P\+ID está ativo para aplicar as tensão necessárias.

Tempo aguardado para cada rotação é de 10k micro segundos (100 Hz)
\begin{DoxyItemize}
\item \begin{DoxyReturn}{Returns}
Retorna um Ponteiro Para Null 
\end{DoxyReturn}

\end{DoxyItemize}

Definition at line 209 of file quanser\+Interface.\+c.

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

\end{DoxyCode}
\mbox{\Hypertarget{quanserInterface_8h_a72cb6672e7a2002cb3eed86f8d58781f}\label{quanserInterface_8h_a72cb6672e7a2002cb3eed86f8d58781f}} 
\index{quanserInterface.h@{quanserInterface.h}!handlePwm@{handlePwm}}
\index{handlePwm@{handlePwm}!quanserInterface.h@{quanserInterface.h}}
\doxysubsubsection{\texorpdfstring{handlePwm()}{handlePwm()}}
{\footnotesize\ttfamily int handle\+Pwm (\begin{DoxyParamCaption}\item[{int}]{dc\+Amount }\end{DoxyParamCaption})}

Função para setar P\+WM e habilitar P\+WM e ponte H. Rotina responsável por setar o valor do duty cycle em função do valor de tensão passado por parâmetro. 

Também é papel desta função de habilitar o pino de enable ponte h e setar o período do P\+WM,

\begin{DoxyParams}{Parameters}
{\em dc\+Amount} & Valor em nano segundos do Duty Cycle a ser aplicado \\
\hline
\end{DoxyParams}
\begin{DoxyReturn}{Returns}
Retorna Positivo Caso Consiga Setar um novo Duty Cycle. 
\end{DoxyReturn}

Definition at line 35 of file quanser\+Interface.\+c.

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

\end{DoxyCode}
\mbox{\Hypertarget{quanserInterface_8h_aae0d60cf64732012d55de41aa4ed5d75}\label{quanserInterface_8h_aae0d60cf64732012d55de41aa4ed5d75}} 
\index{quanserInterface.h@{quanserInterface.h}!jointPositionLimitOneHandler@{jointPositionLimitOneHandler}}
\index{jointPositionLimitOneHandler@{jointPositionLimitOneHandler}!quanserInterface.h@{quanserInterface.h}}
\doxysubsubsection{\texorpdfstring{jointPositionLimitOneHandler()}{jointPositionLimitOneHandler()}}
{\footnotesize\ttfamily void$\ast$ joint\+Position\+Limit\+One\+Handler (\begin{DoxyParamCaption}{ }\end{DoxyParamCaption})}

Thread Um de interrupções de fim de curso. Thread responsável por escutar interrupções de fim de curso assim como fazer a pausa do motor e o desligamento do P\+ID. 

Interrupções sensíveis aos níveis de borda de subida e descida

\begin{DoxyReturn}{Returns}
Retorna um Ponteiro Para Null 
\end{DoxyReturn}

Definition at line 109 of file quanser\+Interface.\+c.

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

\end{DoxyCode}
\mbox{\Hypertarget{quanserInterface_8h_af380e7b0608373355426a5ba9382824c}\label{quanserInterface_8h_af380e7b0608373355426a5ba9382824c}} 
\index{quanserInterface.h@{quanserInterface.h}!jointPositionLimitTwoHandler@{jointPositionLimitTwoHandler}}
\index{jointPositionLimitTwoHandler@{jointPositionLimitTwoHandler}!quanserInterface.h@{quanserInterface.h}}
\doxysubsubsection{\texorpdfstring{jointPositionLimitTwoHandler()}{jointPositionLimitTwoHandler()}}
{\footnotesize\ttfamily void$\ast$ joint\+Position\+Limit\+Two\+Handler (\begin{DoxyParamCaption}{ }\end{DoxyParamCaption})}

Thread Dois de interrupções de fim de curso. Thread Reponseavel por escutar interrupcoes de fim de curso assim como fazer a pausa do motor e o desligamento do P\+ID. 

Interrupções sensíveis aos níveis de borda de subida e descida

\begin{DoxyReturn}{Returns}
Retorna um Ponteiro Para Null 
\end{DoxyReturn}

Definition at line 158 of file quanser\+Interface.\+c.

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

\end{DoxyCode}
\mbox{\Hypertarget{quanserInterface_8h_a0cd1c4a8a39f9776767a0a1c843e51f1}\label{quanserInterface_8h_a0cd1c4a8a39f9776767a0a1c843e51f1}} 
\index{quanserInterface.h@{quanserInterface.h}!qserBreak@{qserBreak}}
\index{qserBreak@{qserBreak}!quanserInterface.h@{quanserInterface.h}}
\doxysubsubsection{\texorpdfstring{qserBreak()}{qserBreak()}}
{\footnotesize\ttfamily int qser\+Break (\begin{DoxyParamCaption}{ }\end{DoxyParamCaption})}

Função responsável por desabilitar a ponte h. Rotina responsável por desabilitar a Ponte H. 

\begin{DoxyReturn}{Returns}
Retorna Positivo Caso Consiga Desabilitar. 
\end{DoxyReturn}

Definition at line 74 of file quanser\+Interface.\+c.

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

\end{DoxyCode}
\mbox{\Hypertarget{quanserInterface_8h_a2cb713f85c500012763209e2ffc0acf7}\label{quanserInterface_8h_a2cb713f85c500012763209e2ffc0acf7}} 
\index{quanserInterface.h@{quanserInterface.h}!qserInitializer@{qserInitializer}}
\index{qserInitializer@{qserInitializer}!quanserInterface.h@{quanserInterface.h}}
\doxysubsubsection{\texorpdfstring{qserInitializer()}{qserInitializer()}}
{\footnotesize\ttfamily int qser\+Initializer (\begin{DoxyParamCaption}{ }\end{DoxyParamCaption})}

Função para inicialização do decoder e motor. Rotina responsável pela inicialização do motor e também do decoder. 

A princípal função é garantir que os P\+WM, Ponte H, Decoder estão aptos a funcionarem.

\begin{DoxyReturn}{Returns}
Retorna Positivo Caso Consiga inicializar. 
\end{DoxyReturn}

Definition at line 56 of file quanser\+Interface.\+c.

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

\end{DoxyCode}
\mbox{\Hypertarget{quanserInterface_8h_a0c496c62c73c815a5b92cd2935452dbb}\label{quanserInterface_8h_a0c496c62c73c815a5b92cd2935452dbb}} 
\index{quanserInterface.h@{quanserInterface.h}!qserVoltage@{qserVoltage}}
\index{qserVoltage@{qserVoltage}!quanserInterface.h@{quanserInterface.h}}
\doxysubsubsection{\texorpdfstring{qserVoltage()}{qserVoltage()}}
{\footnotesize\ttfamily int qser\+Voltage (\begin{DoxyParamCaption}\item[{float}]{voltage }\end{DoxyParamCaption})}

Função para converter voltagem em duty cycle. Rotina responsável por transformar os valores de tensão em Duty Cycle. 

Esse função tem como objetivo transformar um valor de tensão em um valor correspondente ao percentual de 0 a 100\% do duty cycle

\begin{DoxyParams}{Parameters}
{\em voltage} & Valor da voltagem a ser aplicada no Motor \\
\hline
\end{DoxyParams}
\begin{DoxyReturn}{Returns}
Retorna o Status 1 Caso Consiga Fazer A Alteracao do Duty Cycle 
\end{DoxyReturn}

Definition at line 94 of file quanser\+Interface.\+c.

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

\end{DoxyCode}

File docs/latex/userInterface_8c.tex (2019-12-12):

\hypertarget{userInterface_8c}{}\doxysection{src/user\+Interface/user\+Interface.c File Reference}
\label{userInterface_8c}\index{src/userInterface/userInterface.c@{src/userInterface/userInterface.c}}

Funções para manipular e escrever no terminal.  

{\ttfamily \#include \char`\"{}user\+Interface.\+h\char`\"{}}\newline
\doxysubsection*{Functions}
\begin{DoxyCompactItemize}
\item 
void \mbox{\hyperlink{userInterface_8c_a4b9e2beb67256f2c06b39d24bc83e28d}{print\+User\+Options}} ()
\begin{DoxyCompactList}\small\item\em Função para imprimir opções para usuário. Rotina para imprimir no terminal os comandos possíveis para o usuário. \end{DoxyCompactList}\item 
void \mbox{\hyperlink{userInterface_8c_ad08d5cb2ed8e6805573049fd31dab2db}{print\+User\+Groups\+Name}} ()
\begin{DoxyCompactList}\small\item\em Função para imprimir nome de integrantes. \end{DoxyCompactList}\item 
int \mbox{\hyperlink{userInterface_8c_ace06aeff812973e632f2da24f34dcd39}{resolve\+Option}} (char $\ast$cmd)
\begin{DoxyCompactList}\small\item\em Função de validação de comando. Rotina para mapear a opções digitada pelo usuário no menu de opções. \end{DoxyCompactList}\end{DoxyCompactItemize}

\doxysubsection{Detailed Description}
Funções para manipular e escrever no terminal. 

\begin{DoxyAuthor}{Author}
Rodolfo Viola Carvalho, Gabriel Alexandre Zillmer, Felipe Fuhr Dos Reis 
\end{DoxyAuthor}
\begin{DoxyDate}{Date}
11 Dec 2019 
\end{DoxyDate}

\doxysubsection{Function Documentation}
\mbox{\Hypertarget{userInterface_8c_ad08d5cb2ed8e6805573049fd31dab2db}\label{userInterface_8c_ad08d5cb2ed8e6805573049fd31dab2db}} 
\index{userInterface.c@{userInterface.c}!printUserGroupsName@{printUserGroupsName}}
\index{printUserGroupsName@{printUserGroupsName}!userInterface.c@{userInterface.c}}
\doxysubsubsection{\texorpdfstring{printUserGroupsName()}{printUserGroupsName()}}
{\footnotesize\ttfamily void print\+User\+Groups\+Name (\begin{DoxyParamCaption}{ }\end{DoxyParamCaption})}

Função para imprimir nome de integrantes. 

Rotina para imprimir no terminal os nome dos integrantes do grupo

\begin{DoxyReturn}{Returns}
Void 
\end{DoxyReturn}

Definition at line 56 of file user\+Interface.\+c.

\begin{DoxyCode}{0}
\DoxyCodeLine{56                           \{}
\DoxyCodeLine{57     printf(\textcolor{stringliteral}{"\#\#\#\#\#\#\#\#\#\#\# QSER 2019/2 \#\#\#\#\#\#\#\#\#\#\#\#\#\#\(\backslash\)n"});}
\DoxyCodeLine{58     printf(\textcolor{stringliteral}{"> Rodolfo Viola Carvalho\(\backslash\)n"});}
\DoxyCodeLine{59     printf(\textcolor{stringliteral}{"> Gabriel Alexandre Zillmer\(\backslash\)n"});}
\DoxyCodeLine{60     printf(\textcolor{stringliteral}{"> Felipe Fuhr Dos Reis\(\backslash\)n"});}
\DoxyCodeLine{61     printf(\textcolor{stringliteral}{"\#\#\#\#\#\#\#\#\#\#\#\#\#\#\#\#\#\#\#\#\#\#\#\#\#\#\#\#\#\#\#\#\#\#\#\#\#\#\(\backslash\)n\(\backslash\)n"});}
\DoxyCodeLine{62 \}}

\end{DoxyCode}
\mbox{\Hypertarget{userInterface_8c_a4b9e2beb67256f2c06b39d24bc83e28d}\label{userInterface_8c_a4b9e2beb67256f2c06b39d24bc83e28d}} 
\index{userInterface.c@{userInterface.c}!printUserOptions@{printUserOptions}}
\index{printUserOptions@{printUserOptions}!userInterface.c@{userInterface.c}}
\doxysubsubsection{\texorpdfstring{printUserOptions()}{printUserOptions()}}
{\footnotesize\ttfamily void print\+User\+Options (\begin{DoxyParamCaption}{ }\end{DoxyParamCaption})}

Função para imprimir opções para usuário. Rotina para imprimir no terminal os comandos possíveis para o usuário. 

São Commandos Possíveis\+: Speed, goforv, shiftrad, cleardec, getdec, getdecrad, jpl, break, help e exit

\begin{DoxyReturn}{Returns}
Void 
\end{DoxyReturn}

Definition at line 34 of file user\+Interface.\+c.

\begin{DoxyCode}{0}
\DoxyCodeLine{34                        \{}
\DoxyCodeLine{35     printf(\textcolor{stringliteral}{"\#\#\#\#\#\#\#\#\#\#\# QSER OPTIONS \#\#\#\#\#\#\#\#\#\#\#\#\#\#\(\backslash\)n\(\backslash\)n"});}
\DoxyCodeLine{36     printf(\textcolor{stringliteral}{"-\/-\/> speed [0 -\/ 100] \(\backslash\)n"});}
\DoxyCodeLine{37     printf(\textcolor{stringliteral}{"-\/-\/> goforv [-\/V -\/ +V] \(\backslash\)n"});}
\DoxyCodeLine{38     printf(\textcolor{stringliteral}{"-\/-\/> shiftrad [0 -\/ π] (double value) \(\backslash\)n"});}
\DoxyCodeLine{39     printf(\textcolor{stringliteral}{"-\/-\/> cleardec \(\backslash\)n"});}
\DoxyCodeLine{40     printf(\textcolor{stringliteral}{"-\/-\/> getdec \(\backslash\)n"});}
\DoxyCodeLine{41     printf(\textcolor{stringliteral}{"-\/-\/> getdecrad \(\backslash\)n"});}
\DoxyCodeLine{42     printf(\textcolor{stringliteral}{"-\/-\/> jpl \(\backslash\)n"});}
\DoxyCodeLine{43     printf(\textcolor{stringliteral}{"-\/-\/> break \(\backslash\)n"});}
\DoxyCodeLine{44     printf(\textcolor{stringliteral}{"-\/-\/> help \(\backslash\)n"});}
\DoxyCodeLine{45     printf(\textcolor{stringliteral}{"-\/-\/> exit \(\backslash\)n\(\backslash\)n"});}
\DoxyCodeLine{46     printf(\textcolor{stringliteral}{"\#\#\#\#\#\#\#\#\#\#\#\#\#\#\#\#\#\#\#\#\#\#\#\#\#\#\#\#\#\#\#\#\#\#\#\#\#\#\(\backslash\)n\(\backslash\)n"});}
\DoxyCodeLine{47 \}}

\end{DoxyCode}
\mbox{\Hypertarget{userInterface_8c_ace06aeff812973e632f2da24f34dcd39}\label{userInterface_8c_ace06aeff812973e632f2da24f34dcd39}} 
\index{userInterface.c@{userInterface.c}!resolveOption@{resolveOption}}
\index{resolveOption@{resolveOption}!userInterface.c@{userInterface.c}}
\doxysubsubsection{\texorpdfstring{resolveOption()}{resolveOption()}}
{\footnotesize\ttfamily int resolve\+Option (\begin{DoxyParamCaption}\item[{char $\ast$}]{cmd }\end{DoxyParamCaption})}

Função de validação de comando. Rotina para mapear a opções digitada pelo usuário no menu de opções. 

\begin{DoxyParams}{Parameters}
{\em cmd} & Comando digitado pelo usuário \\
\hline
\end{DoxyParams}
\begin{DoxyReturn}{Returns}
retorna o ID do comando digitado pelo usuário 
\end{DoxyReturn}

Definition at line 70 of file user\+Interface.\+c.

\begin{DoxyCode}{0}
\DoxyCodeLine{70                              \{}
\DoxyCodeLine{71     \textcolor{keywordflow}{if} (strncmp(cmd, \textcolor{stringliteral}{"speed"}, 5) == 0) \{ \textcolor{keywordflow}{return} OPTION\_SPEED; \}}
\DoxyCodeLine{72     \textcolor{keywordflow}{else} \textcolor{keywordflow}{if} (strcmp(cmd, \textcolor{stringliteral}{"jpl\(\backslash\)n"}) == 0) \{ \textcolor{keywordflow}{return} OPTION\_JPL; \}}
\DoxyCodeLine{73     \textcolor{keywordflow}{else} \textcolor{keywordflow}{if} (strncmp(cmd, \textcolor{stringliteral}{"goforv"}, 6) == 0) \{ \textcolor{keywordflow}{return} OPTION\_GO\_FOR\_V; \}}
\DoxyCodeLine{74     \textcolor{keywordflow}{else} \textcolor{keywordflow}{if} (strcmp(cmd, \textcolor{stringliteral}{"break\(\backslash\)n"}) == 0) \{ \textcolor{keywordflow}{return} OPTION\_QSER\_BREAK; \}}
\DoxyCodeLine{75     \textcolor{keywordflow}{else} \textcolor{keywordflow}{if} (strcmp(cmd, \textcolor{stringliteral}{"help\(\backslash\)n"}) == 0) \{ \textcolor{keywordflow}{return} OPTION\_HELP; \}}
\DoxyCodeLine{76     \textcolor{keywordflow}{else} \textcolor{keywordflow}{if} (strcmp(cmd, \textcolor{stringliteral}{"exit\(\backslash\)n"}) == 0) \{ \textcolor{keywordflow}{return} OPTION\_EXIT; \}}
\DoxyCodeLine{77     \textcolor{keywordflow}{else} \textcolor{keywordflow}{if} (strncmp(cmd, \textcolor{stringliteral}{"shiftrad"}, 8) == 0) \{ \textcolor{keywordflow}{return} OPTION\_SHIFT\_RAD; \}}
\DoxyCodeLine{78     \textcolor{keywordflow}{else} \textcolor{keywordflow}{if} (strncmp(cmd, \textcolor{stringliteral}{"setkp"}, 5) == 0) \{ \textcolor{keywordflow}{return} OPTION\_SET\_KP; \}}
\DoxyCodeLine{79     \textcolor{keywordflow}{else} \textcolor{keywordflow}{if} (strncmp(cmd, \textcolor{stringliteral}{"setkd"}, 5) == 0) \{ \textcolor{keywordflow}{return} OPTION\_SET\_KD; \}}
\DoxyCodeLine{80     \textcolor{keywordflow}{else} \textcolor{keywordflow}{if} (strncmp(cmd, \textcolor{stringliteral}{"setki"}, 5) == 0) \{ \textcolor{keywordflow}{return} OPTION\_SET\_KI; \}}
\DoxyCodeLine{81     \textcolor{keywordflow}{else} \textcolor{keywordflow}{if} (strncmp(cmd, \textcolor{stringliteral}{"setccu"}, 6) == 0) \{ \textcolor{keywordflow}{return} OPTION\_SET\_CCU; \}}
\DoxyCodeLine{82     \textcolor{keywordflow}{else} \textcolor{keywordflow}{if} (strcmp(cmd, \textcolor{stringliteral}{"cleardec\(\backslash\)n"}) == 0) \{ \textcolor{keywordflow}{return} OPTION\_CLEAR\_DEC; \}}
\DoxyCodeLine{83     \textcolor{keywordflow}{else} \textcolor{keywordflow}{if} (strcmp(cmd, \textcolor{stringliteral}{"getdec\(\backslash\)n"}) == 0) \{ \textcolor{keywordflow}{return} OPTION\_READ\_DEC; \}}
\DoxyCodeLine{84     \textcolor{keywordflow}{else} \textcolor{keywordflow}{if} (strcmp(cmd, \textcolor{stringliteral}{"getdecrad\(\backslash\)n"}) == 0) \{ \textcolor{keywordflow}{return} OPTION\_READ\_DEC\_RAD; \}}
\DoxyCodeLine{85     \textcolor{keywordflow}{else} \textcolor{keywordflow}{return} \mbox{\hyperlink{userInterface_8h_a58a559802dc87f303b0505b79f28a4fc}{OPTION\_INVALID}};}
\DoxyCodeLine{86 \}}

\end{DoxyCode}

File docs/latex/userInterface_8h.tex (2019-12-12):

\hypertarget{userInterface_8h}{}\doxysection{src/user\+Interface/user\+Interface.h File Reference}
\label{userInterface_8h}\index{src/userInterface/userInterface.h@{src/userInterface/userInterface.h}}

Arquivo de cabeçalho para a interface do usuário.  

{\ttfamily \#include $<$stdio.\+h$>$}\newline
{\ttfamily \#include $<$string.\+h$>$}\newline
\doxysubsection*{Macros}
\begin{DoxyCompactItemize}
\item 
\mbox{\Hypertarget{userInterface_8h_a58a559802dc87f303b0505b79f28a4fc}\label{userInterface_8h_a58a559802dc87f303b0505b79f28a4fc}} 
\#define \mbox{\hyperlink{userInterface_8h_a58a559802dc87f303b0505b79f28a4fc}{O\+P\+T\+I\+O\+N\+\_\+\+I\+N\+V\+A\+L\+ID}}~0
\begin{DoxyCompactList}\small\item\em Define os Ids para as opções para o menu. \end{DoxyCompactList}\item 
\mbox{\Hypertarget{userInterface_8h_a472eff3daee8fab8a7de9cd3e1af9626}\label{userInterface_8h_a472eff3daee8fab8a7de9cd3e1af9626}} 
\#define {\bfseries O\+P\+T\+I\+O\+N\+\_\+\+E\+X\+IT}~1
\item 
\mbox{\Hypertarget{userInterface_8h_af8c78c47d312521ecb9ea0117d25009e}\label{userInterface_8h_af8c78c47d312521ecb9ea0117d25009e}} 
\#define {\bfseries O\+P\+T\+I\+O\+N\+\_\+\+H\+E\+LP}~2
\item 
\mbox{\Hypertarget{userInterface_8h_a700124718ddc0a99c0c3627119af32e6}\label{userInterface_8h_a700124718ddc0a99c0c3627119af32e6}} 
\#define {\bfseries O\+P\+T\+I\+O\+N\+\_\+\+S\+P\+E\+ED}~3
\item 
\mbox{\Hypertarget{userInterface_8h_ae94d09b8c155d8741eaa1e8972e40c7c}\label{userInterface_8h_ae94d09b8c155d8741eaa1e8972e40c7c}} 
\#define {\bfseries O\+P\+T\+I\+O\+N\+\_\+\+J\+PL}~4
\item 
\mbox{\Hypertarget{userInterface_8h_a49819416950a2a4323739a5dbb674bcc}\label{userInterface_8h_a49819416950a2a4323739a5dbb674bcc}} 
\#define {\bfseries O\+P\+T\+I\+O\+N\+\_\+\+G\+O\+\_\+\+F\+O\+R\+\_\+V}~5
\item 
\mbox{\Hypertarget{userInterface_8h_a265d171a915f16593b3e6f02698906af}\label{userInterface_8h_a265d171a915f16593b3e6f02698906af}} 
\#define {\bfseries O\+P\+T\+I\+O\+N\+\_\+\+Q\+S\+E\+R\+\_\+\+B\+R\+E\+AK}~6
\item 
\mbox{\Hypertarget{userInterface_8h_a1fa84cb17fbadcf9f9e3bd47f7aa749e}\label{userInterface_8h_a1fa84cb17fbadcf9f9e3bd47f7aa749e}} 
\#define {\bfseries O\+P\+T\+I\+O\+N\+\_\+\+S\+H\+I\+F\+T\+\_\+\+R\+AD}~7
\item 
\mbox{\Hypertarget{userInterface_8h_acc41743904afd8b1f48c22888ae21008}\label{userInterface_8h_acc41743904afd8b1f48c22888ae21008}} 
\#define {\bfseries O\+P\+T\+I\+O\+N\+\_\+\+S\+E\+T\+\_\+\+KP}~8
\item 
\mbox{\Hypertarget{userInterface_8h_a7c29f2416b8f470ca6eb08839ce66955}\label{userInterface_8h_a7c29f2416b8f470ca6eb08839ce66955}} 
\#define {\bfseries O\+P\+T\+I\+O\+N\+\_\+\+S\+E\+T\+\_\+\+KD}~9
\item 
\mbox{\Hypertarget{userInterface_8h_ae0c2cfe65cfbbe0c337edf11baa0023a}\label{userInterface_8h_ae0c2cfe65cfbbe0c337edf11baa0023a}} 
\#define {\bfseries O\+P\+T\+I\+O\+N\+\_\+\+S\+E\+T\+\_\+\+KI}~10
\item 
\mbox{\Hypertarget{userInterface_8h_ab9218a792bac3a40bda1edbf862546ff}\label{userInterface_8h_ab9218a792bac3a40bda1edbf862546ff}} 
\#define {\bfseries O\+P\+T\+I\+O\+N\+\_\+\+S\+E\+T\+\_\+\+C\+CU}~11
\item 
\mbox{\Hypertarget{userInterface_8h_ab2951ecba62167bf10a0650cc986a622}\label{userInterface_8h_ab2951ecba62167bf10a0650cc986a622}} 
\#define {\bfseries O\+P\+T\+I\+O\+N\+\_\+\+C\+L\+E\+A\+R\+\_\+\+D\+EC}~12
\item 
\mbox{\Hypertarget{userInterface_8h_a48ba51fa967838089bffa25a8dc4f2c2}\label{userInterface_8h_a48ba51fa967838089bffa25a8dc4f2c2}}
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

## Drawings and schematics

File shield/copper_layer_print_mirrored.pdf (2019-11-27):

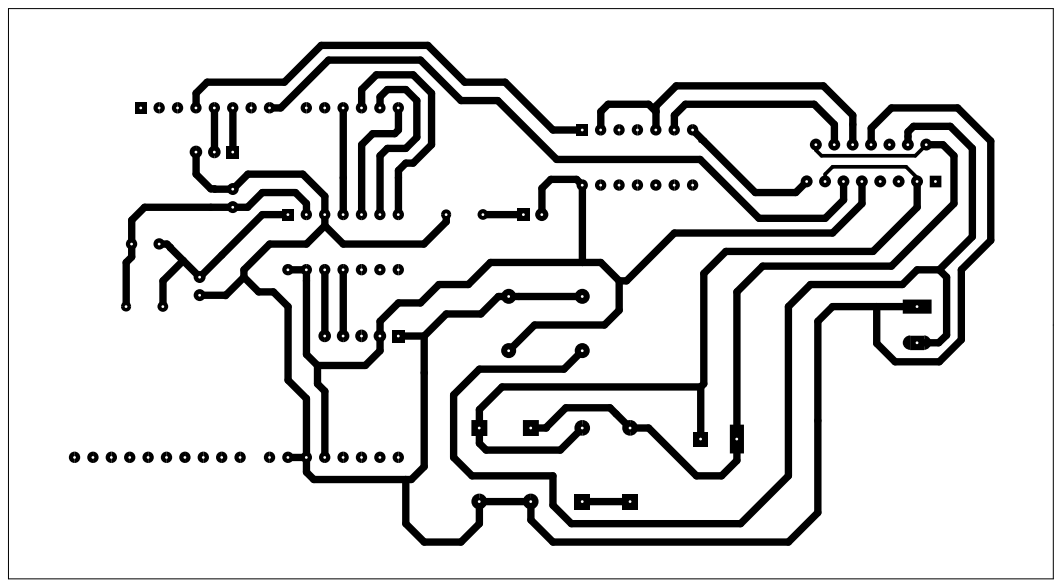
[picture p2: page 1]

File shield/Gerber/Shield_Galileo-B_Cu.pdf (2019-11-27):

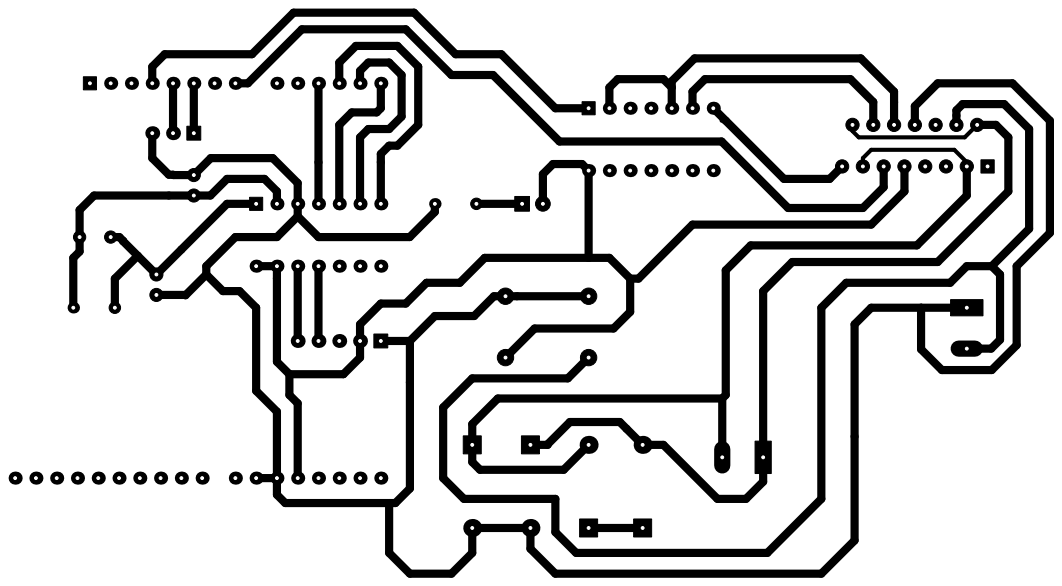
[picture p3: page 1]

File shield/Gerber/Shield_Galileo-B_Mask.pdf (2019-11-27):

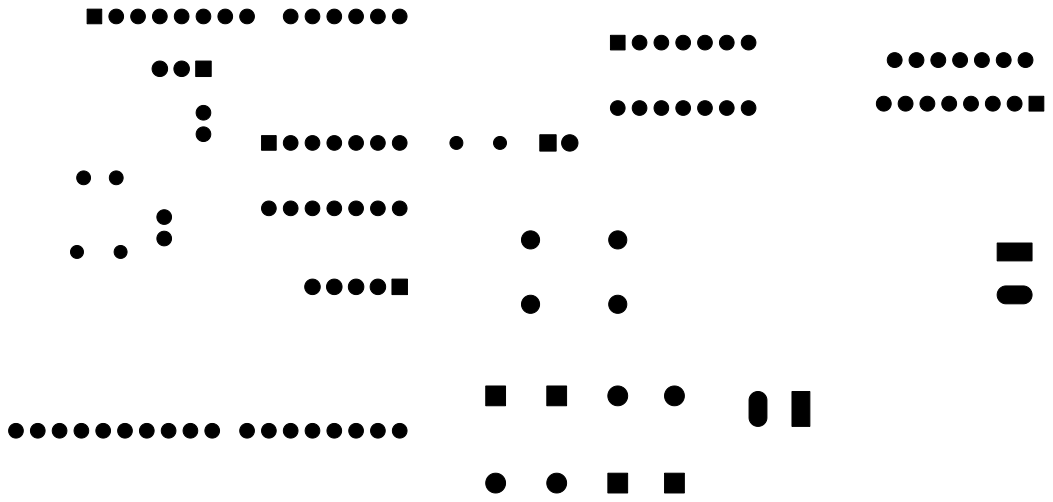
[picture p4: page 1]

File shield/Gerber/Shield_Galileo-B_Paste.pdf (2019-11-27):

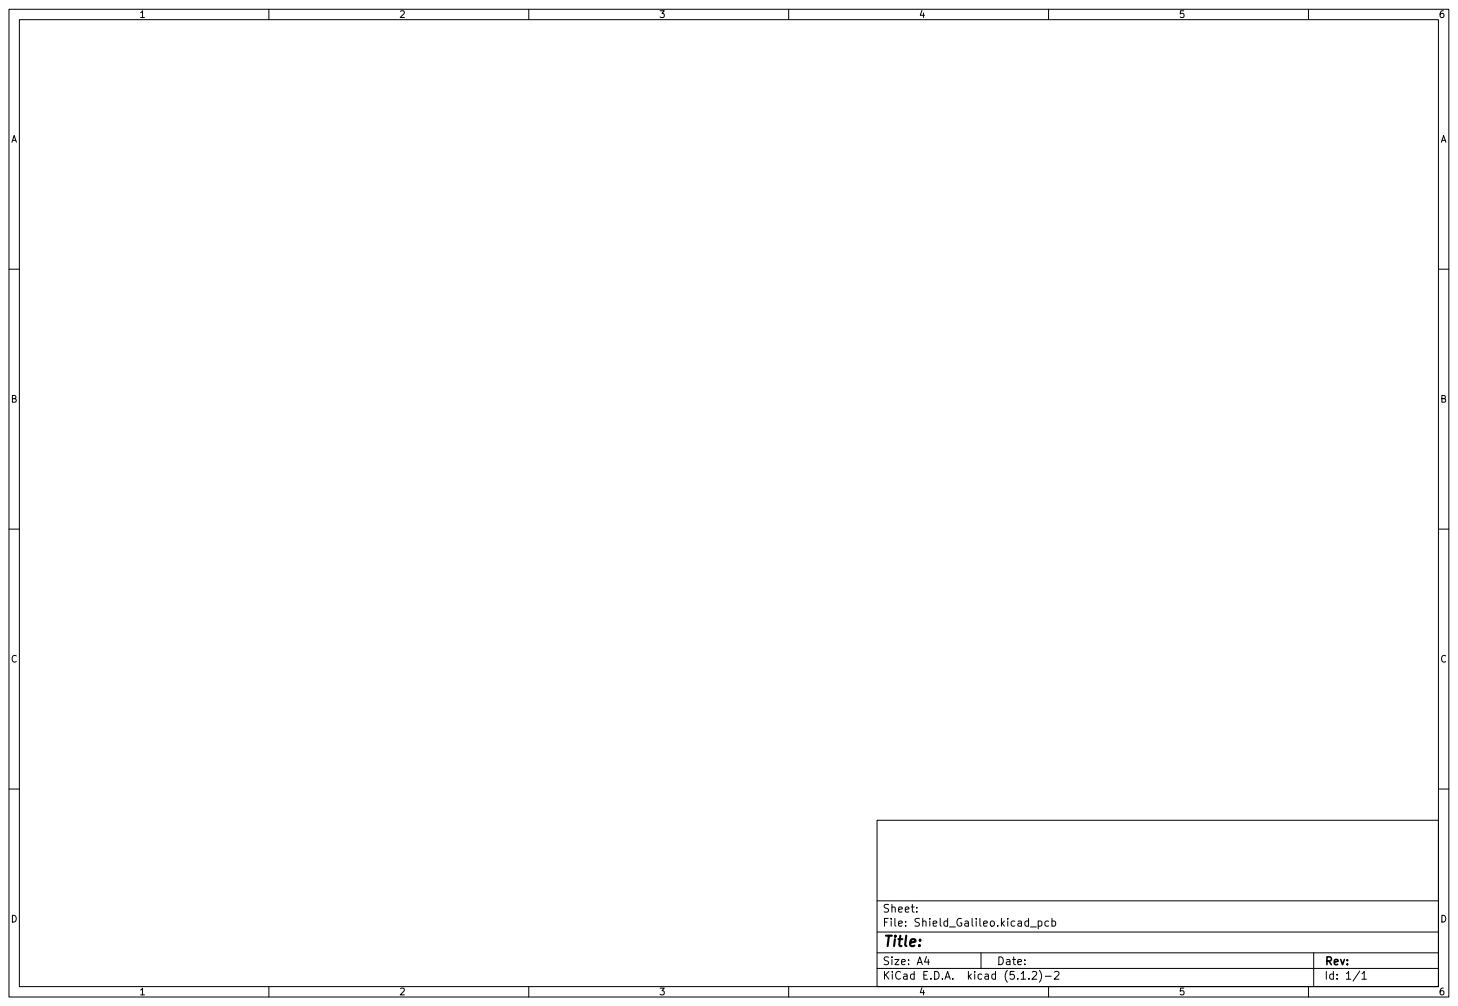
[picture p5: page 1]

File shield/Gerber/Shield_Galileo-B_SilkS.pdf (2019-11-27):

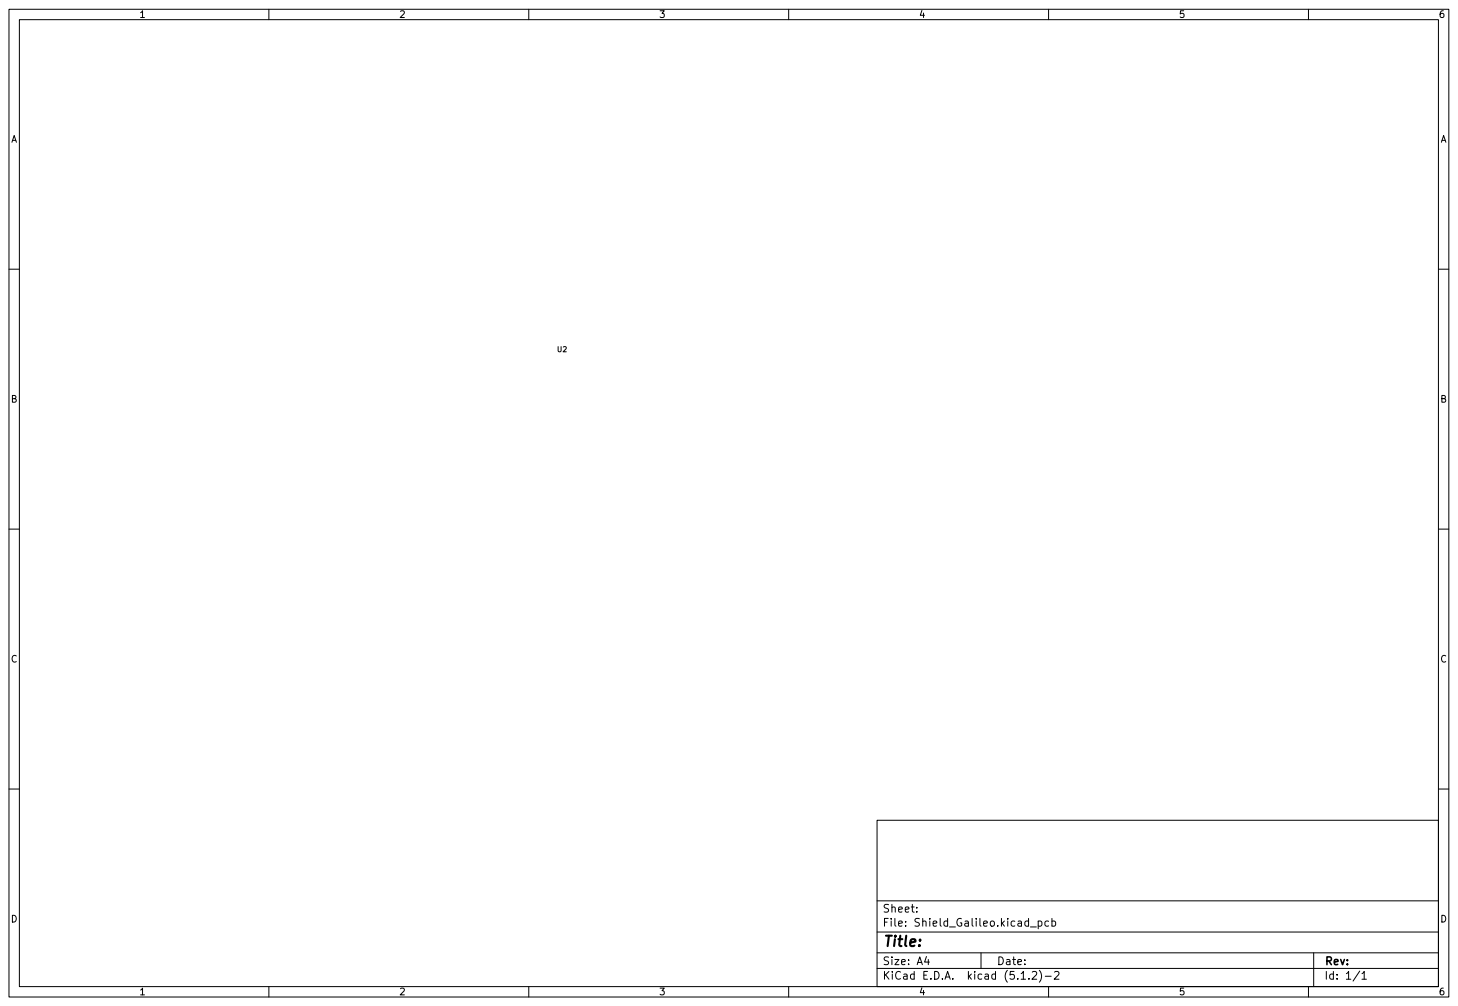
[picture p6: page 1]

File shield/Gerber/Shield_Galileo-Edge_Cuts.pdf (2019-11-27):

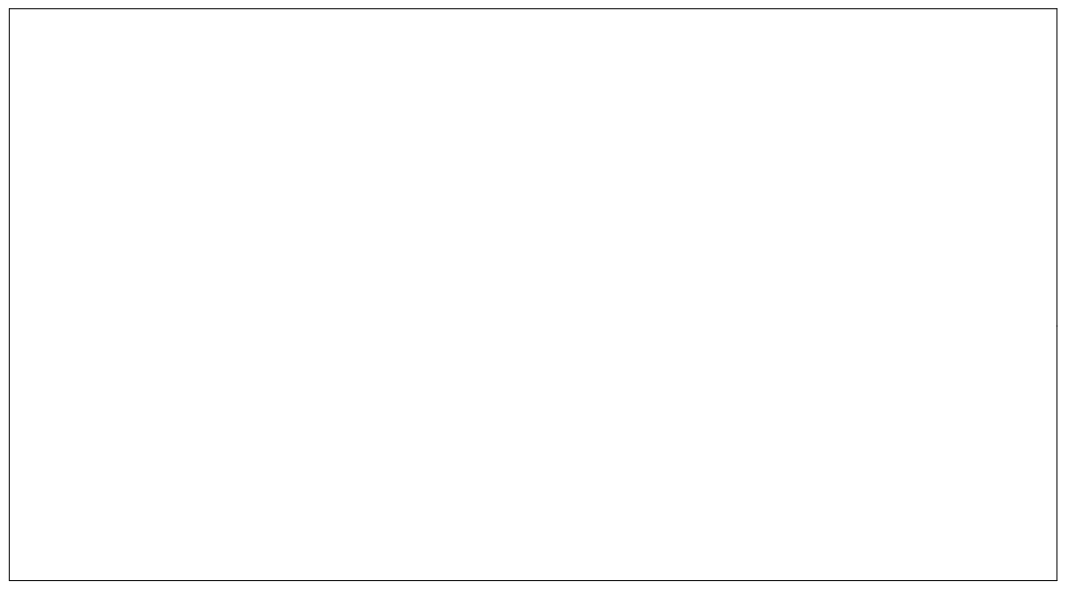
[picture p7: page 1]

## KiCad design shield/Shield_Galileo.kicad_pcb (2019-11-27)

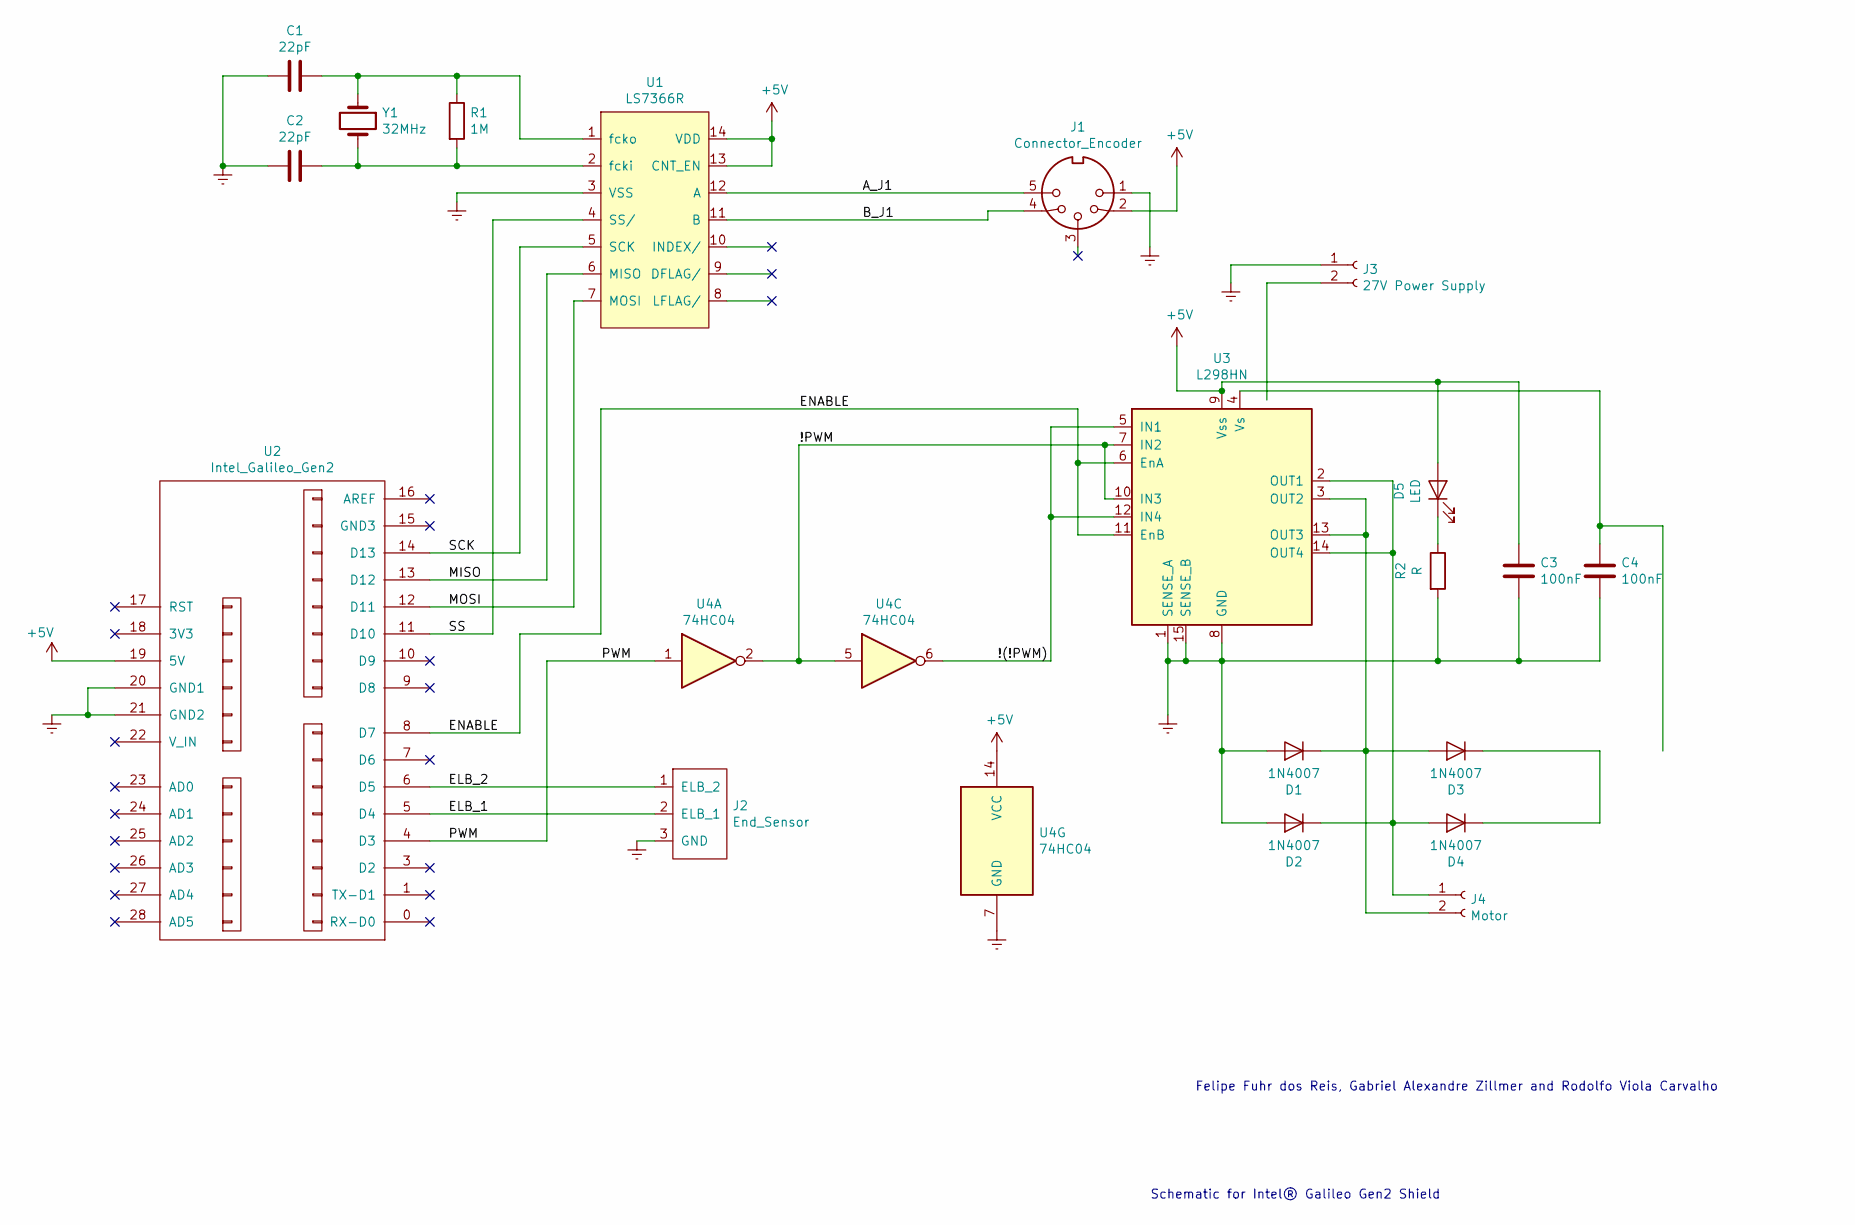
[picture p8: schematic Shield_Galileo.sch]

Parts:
C1, C2: 22pF; C_Disc_D3.0mm_W2.0mm_P2.50mm
C3, C4: 100nF; C_Disc_D10.5mm_W5.0mm_P7.50mm
D1, D2, D3, D4: 1N4007; D_DO-41_SOD81_P10.16mm_Horizontal
D5: LED; LED_D5.0mm
J1: Connector_Encoder; PinHeader_1x05_P2.54mm_Vertical
J2: End_Sensor; PinHeader_1x03_P2.54mm_Vertical
J3: 27V Power Supply; TerminalBlock_Altech_AK300-2_P5.00mm
J4: Motor; TerminalBlock_Altech_AK300-2_P5.00mm
R1: 1M; R_Axial_DIN0204_L3.6mm_D1.6mm_P5.08mm_Horizontal
R2: R; R_Axial_DIN0204_L3.6mm_D1.6mm_P5.08mm_Horizontal
U1: LS7366R; DIP-14_W7.62mm
U2: Intel_Galileo_Gen2; Intel_Galileo_Gen2_Pins
U3: L298HN; TO127P2020X500X2100-15
U4: 74HC04; DIP-14_W7.62mm
Y1: 32MHz; Crystal_HC52-6mm_Vertical

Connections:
+5V: C3.1, D5.2 (A), J1.2, U1.13 (CNT_EN), U1.14 (VDD), U2.19 (5V), U3.9 (Vss), U4.14 (VCC)
/!(!PWM): U3.5 (IN1), U3.12 (IN4), U4.6
/!PWM: U3.7 (IN2), U3.10 (IN3), U4.2, U4.5
/A_J1: J1.5, U1.12 (A)
/B_J1: J1.4, U1.11 (B)
/ELB_1: J2.2 (ELB_1), U2.5 (D4)
/ELB_2: J2.1 (ELB_2), U2.6 (D5)
/ENABLE: U2.8 (D7), U3.6 (EnA), U3.11 (EnB)
/MISO: U1.6 (MISO), U2.13 (D12)
/MOSI: U1.7 (MOSI), U2.12 (D11)
/PWM: U2.4 (D3), U4.1
/SCK: U1.5 (SCK), U2.14 (D13)
/SS: U1.4 (SS/), U2.11 (D10)
Earth: C1.2, C2.2, C3.2, C4.2, D1.2 (A), D2.2 (A), J1.1, J2.3 (GND), J3.1, R2.2, U1.3 (VSS), U2.20 (GND1), U2.21 (GND2), U3.1 (SENSE_A), U3.8 (GND), U3.15 (SENSE_B), U4.7 (GND)
unnamed: C1.1, R1.1, U1.1 (fcko), Y1.1
unnamed: C2.1, R1.2, U1.2 (fcki), Y1.2
unnamed: D1.1 (K), D3.2 (A), J4.2, U3.3 (OUT2), U3.13 (OUT3)
unnamed: D2.1 (K), D4.2 (A), J4.1, U3.2 (OUT1), U3.14 (OUT4)
unnamed: D3.1 (K), D4.1 (K)
unnamed: D5.1 (K), R2.1

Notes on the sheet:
Felipe Fuhr dos Reis, Gabriel Alexandre Zillmer and Rodolfo Viola Carvalho
Schematic for Intel® Galileo Gen2 Shield

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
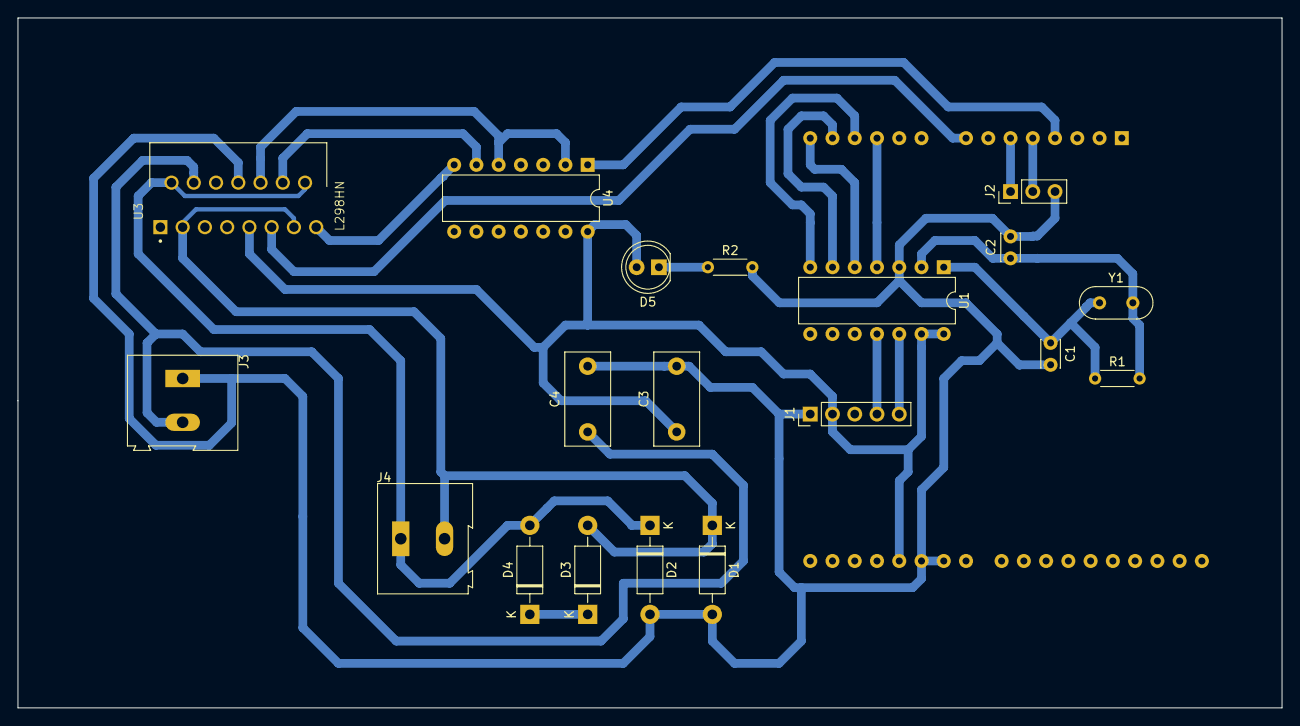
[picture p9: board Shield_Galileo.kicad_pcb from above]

Board: 2 copper layers, 144.3 x 78.7 mm, 20 parts (1 on the bottom side), 21 nets.

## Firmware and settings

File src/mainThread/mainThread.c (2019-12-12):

// Qser Aplication
// Copyright (C) 2019 Rodolfo Viola Carvalho, Gabriel Alexandre Zillmer, Felipe Fuhr Dos Reis
//
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
/**
 * @file mainThread.c
 * @author Rodolfo Viola Carvalho, Gabriel Alexandre Zillmer, Felipe Fuhr Dos Reis
 * @date 11 Dec 2019
 * @brief  Thread Principal para controlar fluxo do usuário e comandos.
 */

#include "mainThread.h"
/** @brief Status do final de curso um */
int JPL_REACHED_STATUS_ONE = 0;
/** @brief Status do final de curso dois */
int JPL_REACHED_STATUS_TWO = 0;


/**
 * @brief Main Thread para interface com usuário e controle de fluxo.
 * Thread responsável por esperar comando do usuário e fazer a chamad necessária da API para executar a ação.
 *
 * É nessa thread que é feita excutada as funções da biblioteca, repetidamente espera em um loop infito um comando de um usuário
 * para sair e encerrar o programa é necessario um comando Exit.
 *
 * @return Retorna um Ponteiro para Null
 */
void* handlerMainThread() {
    if(DEBUG) printf("[DEBUG] - Starting handlerMainThread \n");
    printUserGroupsName();
    printUserOptions();

    char command[100];
    while (fgets(command, sizeof(command), stdin)) {
        if(DEBUG) printf("[DEBUG] - Inside Command While MainThread \n");
        switch (resolveOption(command)) {
            case OPTION_SPEED: {
                if(DEBUG) printf("[DEBUG] - Got SPEED Option MainThread \n");
                float commandAmount = atof(&command[6]);
                if(commandAmount > 100 || commandAmount < 0) {
                    printf("[ERROR] - Speed Amount Must Be [0-100]\n");
                } else {
                    if(DEBUG) printf("[DEBUG] - Got Valid Speed Number MainThread \n");
                    float dcAmount = (commandAmount/100)*atof(PWM_PERIOD);
                    if(handlePwm((int)dcAmount) == 1) {
                        fprintf(stdout, "[INFO] MT - Motor Duty Cycle %d%%\n\n", (int)dcAmount/10000);
                    } else {
                        printf("[ERROR] MT - Error Turning On Motor\n\n");
                    }
                }
                break;
            }
            case OPTION_JPL: {
                if(DEBUG) printf("[DEBUG] - Got JPL Option MainThread \n");
                if(JPL_REACHED_STATUS_ONE == JPL_REACHED){
                    printf("[INFO] MT - JPL ONE Reached The End. State: Active [ %d ]\n", JPL_REACHED_STATUS_ONE);
                } else printf("[INFO] MT - READ JPL ONE. State: Inactive [ %d ]\n", JPL_REACHED_STATUS_ONE);
                if(JPL_REACHED_STATUS_TWO == JPL_REACHED){
                    printf("[INFO] MT - JPL TWO Reached The End. State: Active [ %d ]\n\n", JPL_REACHED_STATUS_TWO);
                } else printf("[INFO] MT - READ JPL TWO. State: Inactive [ %d ]\n\n", JPL_REACHED_STATUS_TWO);
                break;
            }
            case OPTION_GO_FOR_V: {
                if(DEBUG) printf("[DEBUG] - Got GO FOR V Option MainThread \n");
                float commandAmount = atof(&command[7]);
                if(commandAmount < -QSER_VOLTAGE || commandAmount > QSER_VOLTAGE) {
                    fprintf(stderr, "[ERROR] - Voltage Must Be On The Interval [%+d,%+d]\n", (int) -QSER_VOLTAGE, (int) QSER_VOLTAGE);
                } else {
                    if(DEBUG) printf("[DEBUG] MT - Got Accepted Voltage \n");
                    if(qserVoltage(commandAmount) == 1)	{
                        fprintf(stdout, "[INFO] - Motor Triggered With Voltage  %+.1fV\n\n", commandAmount);
                    } else {
                        fprintf(stdout, "[ERROR] - Something Went Wrong Trying To Turn On Motor\n\n");
                    }
                }
                break;
            }
            case OPTION_QSER_BREAK: {
                if(DEBUG) printf("[DEBUG] - Got QSER BREAK Option MainThread\n");
                if(qserBreak() == TRUE){
                    turnOffPid();
                    printf("[INFO] - Breaking Motor\n");
                } else {
                    fprintf(stdout, "[ERROR] - Something Went Wrong Trying To Break Motor\n\n");
                }
                break;
            }
                /** @brief  Função para Setar Posição de Target em Radianos.
                 *
                 * Essa Rotina é responsável por fazer o cálculo de conversão de Radianos para uma posição do motor;
                 * Do datasheet do motor temos que 1 revolução é igual a 4096 counts.
                 * (4096 / 360) = 1 grau ou 0.0174533 rad
                 *
                 */
            case OPTION_SHIFT_RAD: {
                if(DEBUG) printf("[DEBUG] - Got OPTION_SHIFT_RAD Option MainThread\n");
                double commandAmount = (double)strtof(&command[9], NULL);
                if(commandAmount < 0 || commandAmount > PI){
                    printf("[Error] - Radian Must Be On The Interval [0, %f] \n", PI);
                    break;
                }
                int targetMotorPosition = commandAmount * (MAX_RANGE / PI) * MOTOR_REVOLUTIONS;
                setTarget(targetMotorPosition);
                turnOnPid();
                break;
            }
            case OPTION_SET_KD: {
                if(DEBUG) printf("[DEBUG] - Got OPTION_SET_KD Option MainThread \n");
                double commandAmount = (double)strtof(&command[6], NULL);
                setControlKd(commandAmount);
                break;
            }
            case OPTION_SET_KP: {
                if(DEBUG) printf("[DEBUG] - Got OPTION_SET_KP Option MainThread \n");
                double commandAmount = (double)strtof(&command[6], NULL);
                setControlKp(commandAmount);
                break;
            }
            case OPTION_SET_KI: {
                if(DEBUG) printf("[DEBUG] - Got OPTION_SET_KI Option MainThread \n");
                double commandAmount = (double)strtof(&command[6], NULL);
                setControlKi(commandAmount);
                break;
            }
            case OPTION_CLEAR_DEC: {
                if(DEBUG) printf("[DEBUG] - Got OPTION_CLEAR_DEC Option MainThread\n");
                clearDecoder();
                printf("[INFO] - Cleaning Decoder\n\n");
                break;
            }
            case OPTION_READ_DEC: {
                if(DEBUG) printf("[DEBUG] - Got OPTION_READ_DEC Option MainThread\n");
                int counterDecoder = readDecoderCounter();
                printf("[INFO] - Decoder Reading: %d \n\n", counterDecoder);
                break;
            }
            /** @brief  Leitura do decoder e transformação para Radianos.
             *
             * Essa Rotina é responsável por fazer o cálculo de conversão da leitura do decoder para posição em radianos;
             * Do datasheet do motor temos que 1 revolução é igual a 4096 counts.
             * (4096 / 360) = 1 grau ou 0.0174533 rad
             *
             * */
            case OPTION_READ_DEC_RAD: {
                if(DEBUG) printf("[DEBUG] - Got OPTION_READ_DEC_RAD Option MainThread\n");
                int counterDecoder = readDecoderCounter();
                double revCount = (float)counterDecoder / MOTOR_REVOLUTIONS;
                double radDec = revCount * PI / MAX_RANGE;
                printf("[INFO] - Decoder Reading: %f \n\n", radDec);
                break;
            }
            case OPTION_HELP: {
                if(DEBUG) printf("[DEBUG] - Got HELP Option MainThread\n");
                printUserOptions();
                break;
            }
            case OPTION_EXIT: {
                if(DEBUG) printf("[DEBUG] - Got EXIT Option MainThread\n");
                qserBreak();
                turnOffPid();
                wrapUpDecoder();
                printf("[INFO] - Finishing Application...\n");
                exit(0);
            }
            case OPTION_INVALID: {
                if(DEBUG) printf("[DEBUG] - Got INVALID Option MainThread\n");
                printf("[ERROR] - Command Invalid Type Help For The Command List\n");
                break;
            }
            default: {
                if(DEBUG) printf("[DEBUG] - Got DEFAULT Option MainThread\n");
                printf("[ERROR] - Command Invalid Type Help For The Command List\n");
            }
        }
    }
    return NULL;
}

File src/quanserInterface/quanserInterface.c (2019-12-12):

// Qser Aplication
// Copyright (C) 2019 Rodolfo Viola Carvalho, Gabriel Alexandre Zillmer, Felipe Fuhr Dos Reis
//
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
/**
 * @file quanserInterface.c
 * @author Rodolfo Viola Carvalho, Gabriel Alexandre Zillmer, Felipe Fuhr Dos Reis
 * @date 11 Dec 2019
 * @brief  Funções para funcionamento do Motor, PWM e Ponte H.
 */

#include "quanserInterface.h"

/**
 * @brief Função para setar PWM e habilitar PWM e ponte H.
 * Rotina responsável por setar o valor do duty cycle em função do valor de tensão passado por parâmetro
 *
 * Também é papel desta função de habilitar o pino de enable ponte h e setar o período do PWM,
 *
 * @param dcAmount Valor em nano segundos do Duty Cycle a ser aplicado
 * @return Retorna Positivo Caso Consiga Setar um novo Duty Cycle.
 */
int handlePwm(int dcAmount) {
    if(DEBUG) printf("[DEBUG] - Starting handlePwm\n");
    if(IS_RUNNING_LOCAL) return TRUE;
    char dataFull[20];
    snprintf(dataFull, sizeof(dataFull), "%d\n", dcAmount);
    if(writeHandler("/sys/class/gpio/gpio38/value", "1") < 0) return FALSE;
    if(writeHandler("/sys/class/pwm/pwmchip0/pwm1/enable", "1") < 0) return FALSE;
    if(writeHandler("/sys/class/pwm/pwmchip0/device/pwm_period", PWM_PERIOD) < 0) return FALSE;
    if(writeHandler("/sys/class/pwm/pwmchip0/pwm1/duty_cycle", dataFull) < 0) return FALSE;
    if(DEBUG) printf("[DEBUG] - Finishing handlePwm");
    return TRUE;
}

/**
 * @brief Função para inicialização do decoder e motor.
 * Rotina responsável pela inicialização do motor e também do decoder.
 *
 * A princípal função é garantir que os PWM, Ponte H, Decoder estão aptos a funcionarem.
 *
 * @return Retorna Positivo Caso Consiga inicializar.
 */
int qserInitializer() {
    if(DEBUG) printf("[INFO] - Initializing Qser \n");
    int initialPwaValue = 0;
    if(handlePwm(initialPwaValue) ==  FALSE){
        fprintf(stderr, "[ERROR] - Error While Trying To Set PWM Initialization\n");
        exit(0);
    }
    qserBreak();
    decoderInitializer(SPI_DEFAULT_SPEED);
    clearDecoder();
    return TRUE;
}

/**
 * @brief Função responsável por desabilitar a ponte h.
 * Rotina responsável por desabilitar a Ponte H
 * @return Retorna Positivo Caso Consiga Desabilitar.
 */
int qserBreak() {
    if(DEBUG) printf("[DEBUG] - Starting qserBreak\n");
    if(IS_RUNNING_LOCAL) return TRUE;
    if(writeHandler("/sys/class/gpio/gpio38/value", "0") < 0) {
        printf("[INFO] - Error Writing qserBreak File Value to Zero");
        return FALSE;
    }
    if(DEBUG) printf("[DEBUG] - Finishing qserBreak\n");
    return TRUE;
}

/**
 * @brief Função para converter voltagem em duty cycle.
 * Rotina responsável por transformar os valores de tensão em Duty Cycle.
 *
 * Esse função tem como objetivo transformar um valor de tensão em um valor correspondente ao percentual de 0 a 100% do duty cycle
 *
 * @param voltage Valor da voltagem a ser aplicada no Motor
 * @return Retorna o Status 1 Caso Consiga Fazer A Alteracao do Duty Cycle
 */
int qserVoltage(float voltage) {
    if(DEBUG) printf("[DEBUG] - Starting qserVoltage\n");
    float dcAmount = (( voltage + QSER_VOLTAGE ) / ( 2 * QSER_VOLTAGE )) * atof(PWM_PERIOD);
    if(DEBUG) printf("[DEBUG] - Finishing qserVoltage\n");
    return handlePwm((int)dcAmount);
}

/**
 * @brief Thread Um de interrupções de fim de curso.
 * Thread responsável por escutar interrupções de fim de curso assim como fazer a pausa do motor e o desligamento do PID.
 *
 * Interrupções sensíveis aos níveis de borda de subida e descida
 *
 * @return Retorna um Ponteiro Para Null
 */
void* jointPositionLimitOneHandler() {
    if(IS_RUNNING_LOCAL) return 0;
    if(DEBUG) printf("[DEBUG] - Starting Joint Position Limiter Handler Thread \n");
    char rootPathLimiterOneValue[100] = "/sys/class/gpio/gpio6/value";
    char rootPathLimiterOneEdge[100] = "/sys/class/gpio/gpio6/edge";

    unsigned char dataOne;
    struct pollfd pollFileHandlerOne;

    if(DEBUG) printf("[DEBUG] - JPL Opening First File GPIO 6\n");
    if((pollFileHandlerOne.fd = open(rootPathLimiterOneValue, O_RDONLY)) < 0) {
        fprintf(stderr, "[ERROR] - Joint Position Limiter One Open File Descriptor Error %s.\n", rootPathLimiterOneValue);
        exit(11);
    }

    read(pollFileHandlerOne.fd,&dataOne,1);

    if(DEBUG) printf("[DEBUG] - Starting Joint Position Limiter Handler While \n");
    int shouldNeverStop = TRUE;
    while(shouldNeverStop) {
        if(DEBUG) printf("[DEBUG] - Checking Joint Position Limiter \n");
        pollFileHandlerOne.events = POLLPRI;
        writeHandler(rootPathLimiterOneEdge,"both");
        poll(&pollFileHandlerOne,1,-1);
        lseek(pollFileHandlerOne.fd,0,SEEK_SET);
        if(DEBUG) printf("[DEBUG] - JPL Reading First File GPIO 0\n");
        if(read(pollFileHandlerOne.fd, &dataOne, 1) < 0) {
            fprintf(stderr, "[ERROR] - JPL One Reading Error %s\n\n", rootPathLimiterOneValue);
            exit(2);
        }
        if(DEBUG) printf("[DEBUG] - JPL Testing For End\n");
        if(dataOne == JPL_REACHED) {
            printf("[INFO] - JPL ONE Reached End \n\n");
            qserBreak();
            turnOffPid();
        }
        JPL_REACHED_STATUS_ONE = dataOne;

    }
    return NULL;
}
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

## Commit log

2019-11-23 Added Main Thread and Scripts To Build Files
2019-11-23 Added User Options Switch
2019-11-24 Added handler for two switches and make file for galileo
2019-11-26 Added break function and fix problem with jpl functions
    [mainThread.c, quanserInterface.c, quanserInterface.h]
2019-11-26 Add schematic and PCB layout
    [Shield_Galileo.dsn, Shield_Galileo.kicad_pcb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]
2019-11-27 Add new Shield files
    [Shield_Galileo.kicad_pcb, Shield_Galileo.sch]
2019-11-29 Change PWM from io6 to io7. Minor changes on init script
2019-12-01 Added PID Controller
2019-12-01 Added PID handler to change voltage
2019-12-01 TurnOff PID missing on JPL and added decoder to makefile
    [quanserInterface.c]
2019-12-06 Added step change speed motor
2019-12-11 Main Thread And Fix Minor Changes
    [decoderInterface.c, mainThread.c]

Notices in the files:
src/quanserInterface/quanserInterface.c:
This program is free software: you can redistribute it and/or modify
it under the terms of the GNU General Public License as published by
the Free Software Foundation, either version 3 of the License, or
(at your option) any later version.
